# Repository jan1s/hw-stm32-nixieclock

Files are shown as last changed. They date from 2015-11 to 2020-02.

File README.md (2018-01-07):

# hw-nixieclock

The firmware running on the clock: [Firmware](https://github.com/jan1s/fw-clock)

A small Gist to configure a STM32 toolchain on Mac: [Toolchain](https://jan1s.github.io)

To flash the controller a STM32 Programmer is needed, just get the cheapest one from China.

## Initial Configuration

Before the clock will actually start working, it is necessary to set the type:

```bash
nixie_settype <type>
nixie_settype <type(0-4)>
```

Where `<type>` is a number defining the nixie clock type.

1. ZM1000
2. Z570M, IN-8
3. ZM1325
4. IN-14, ZM1020

It is also required to set the mode of operation:

```bash
nixie_setmode <mode>
nixie_setmode <mode(0=NONE|1=HHMMSS|2=HHMM|3=MMSS|4=YYYY)>
```

Where `<mode>` is a number defining the nixie operation mode.

1. HH:MM:SS
2. HH:MM
3. MM:SS
4. YYYY

## PCBs

The clock has seperate control and display pcbs. Those pcbs do not only form a basic case for the electronics, but also allow for flexible use with different tubes.

[Control PCBs](layout/control)

[Display PCBs](layout/display)

[Source PCBs](layout/source)

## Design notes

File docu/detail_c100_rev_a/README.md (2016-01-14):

# rev. a prototype in detail

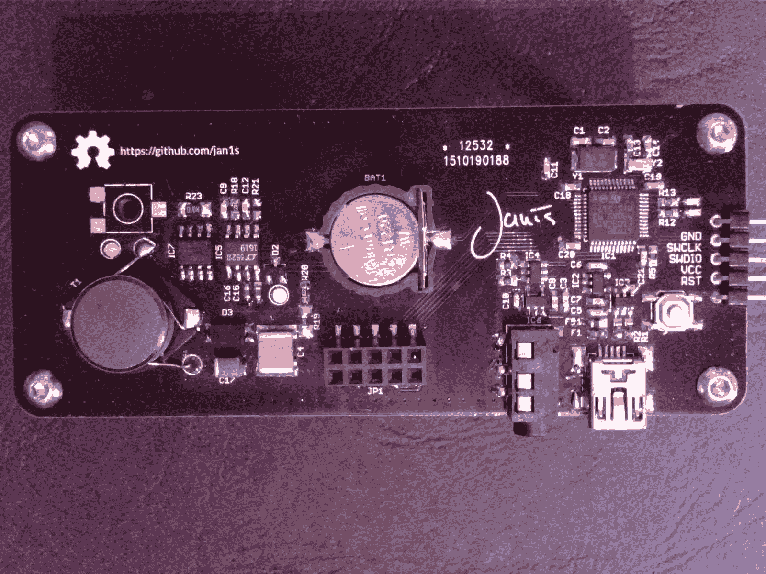
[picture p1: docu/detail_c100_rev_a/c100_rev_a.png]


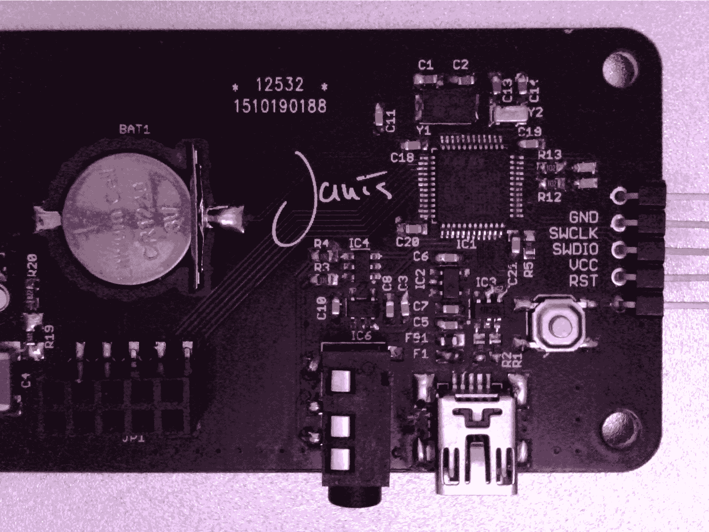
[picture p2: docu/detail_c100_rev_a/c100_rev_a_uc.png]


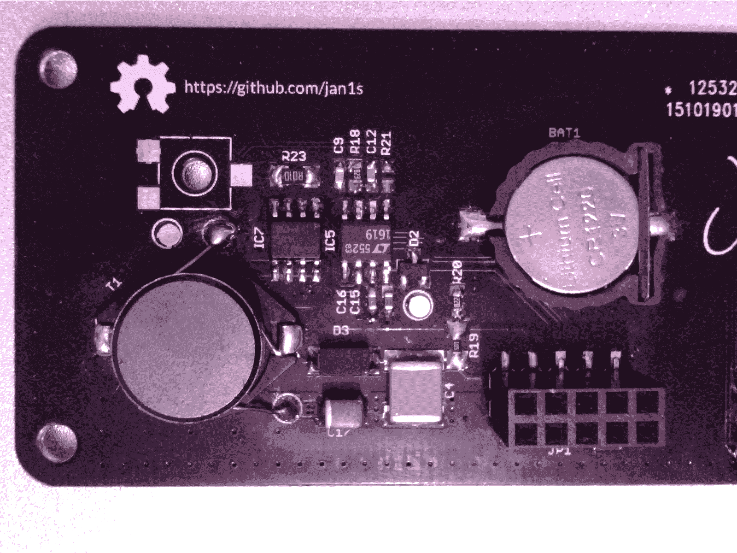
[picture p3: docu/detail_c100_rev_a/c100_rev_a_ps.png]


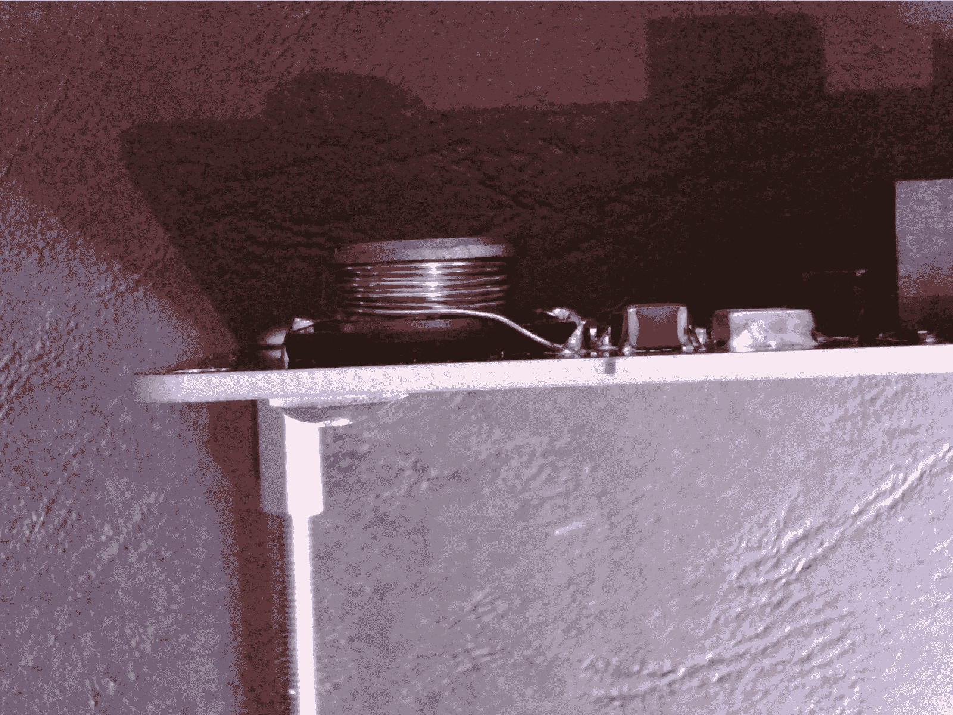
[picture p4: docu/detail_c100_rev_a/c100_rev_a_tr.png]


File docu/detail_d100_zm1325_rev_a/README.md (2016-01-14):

# rev. a prototype in detail

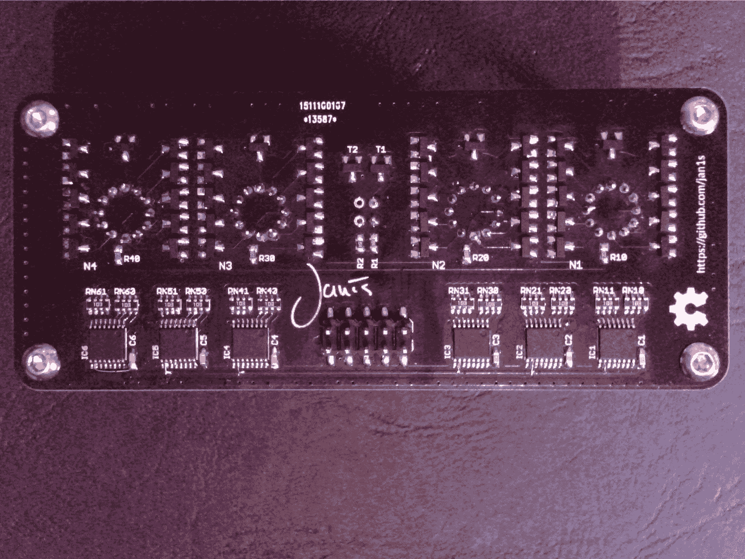
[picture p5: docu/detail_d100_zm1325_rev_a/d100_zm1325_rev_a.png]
Display PCB


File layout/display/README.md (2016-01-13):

# Display PCBs

## d100

The display boards with 100mm width use a smaller variant of the 74hc595 shift register.

### d100 ZM1000

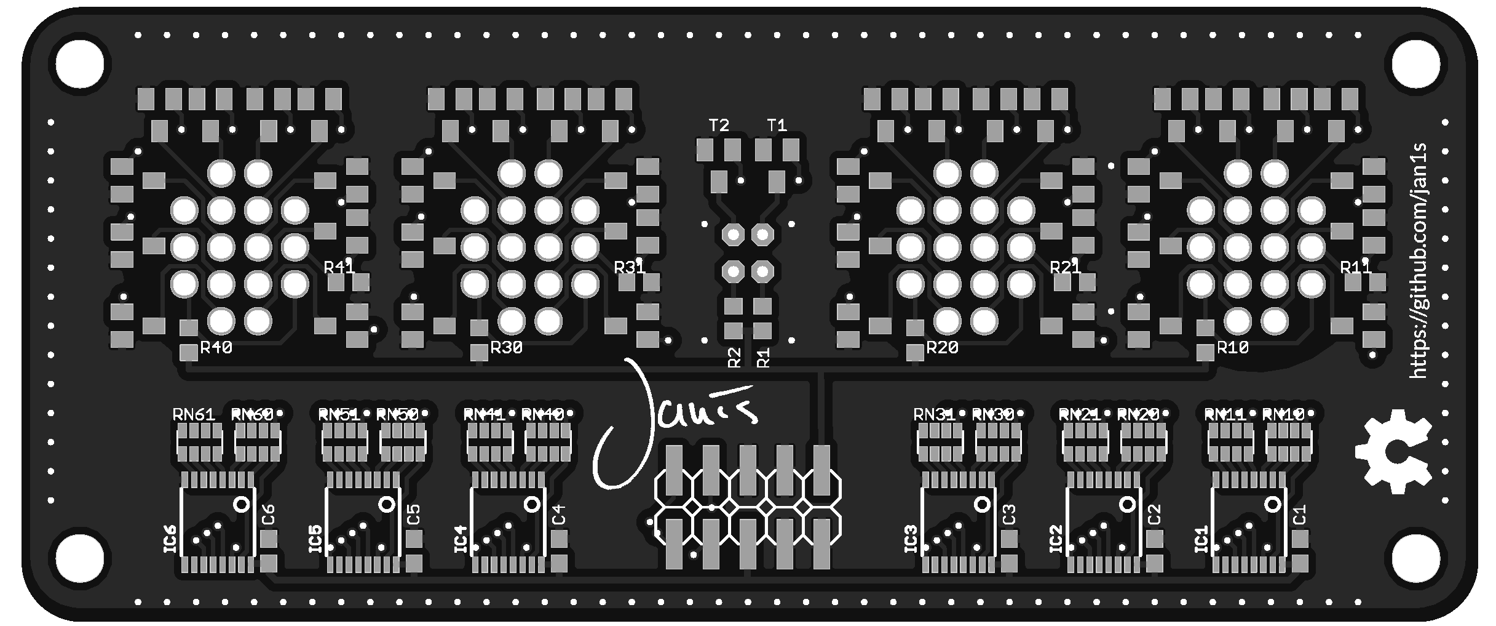
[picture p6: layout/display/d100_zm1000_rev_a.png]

rev. a

In rev a of the PCB is an error. (This is the version from the 32C3 workshop)
Find detailed pictures of the first prototype [here](../../docu/detail_d100_zm1325_rev_a).

* SCL of the shift registers are floating, they need to be connected to 5V

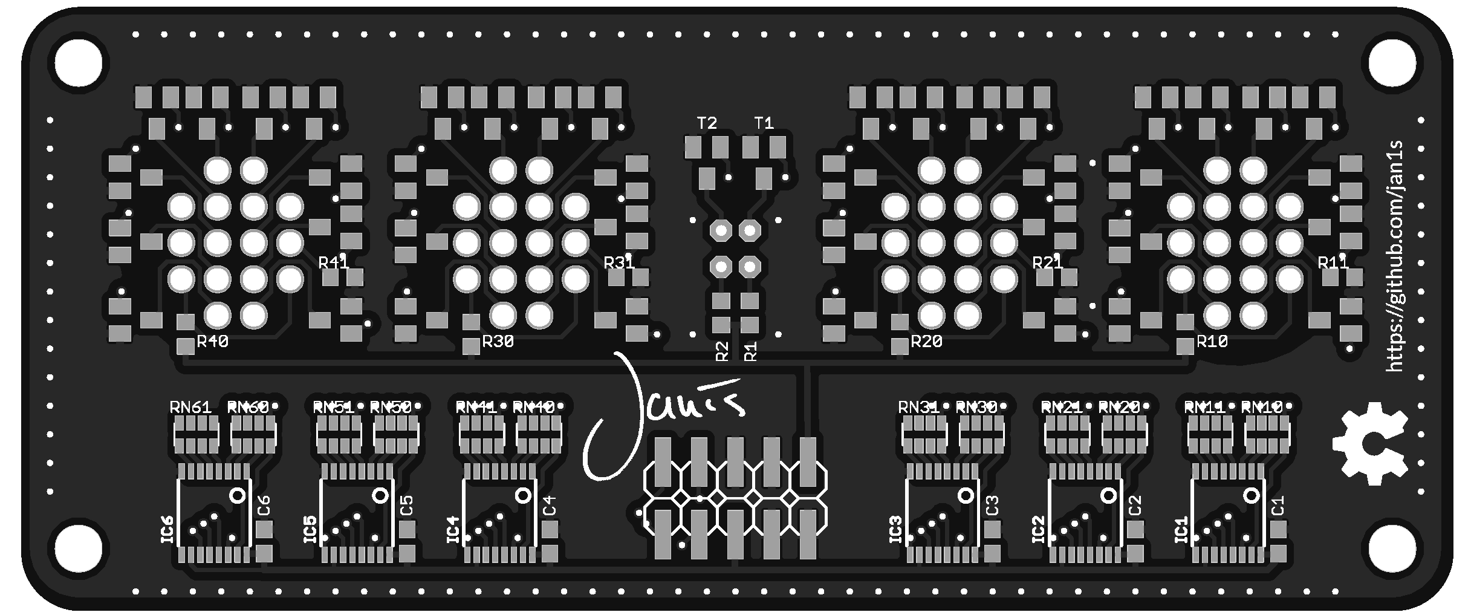
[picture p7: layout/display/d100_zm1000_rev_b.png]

rev. b

### d100 ZM1325

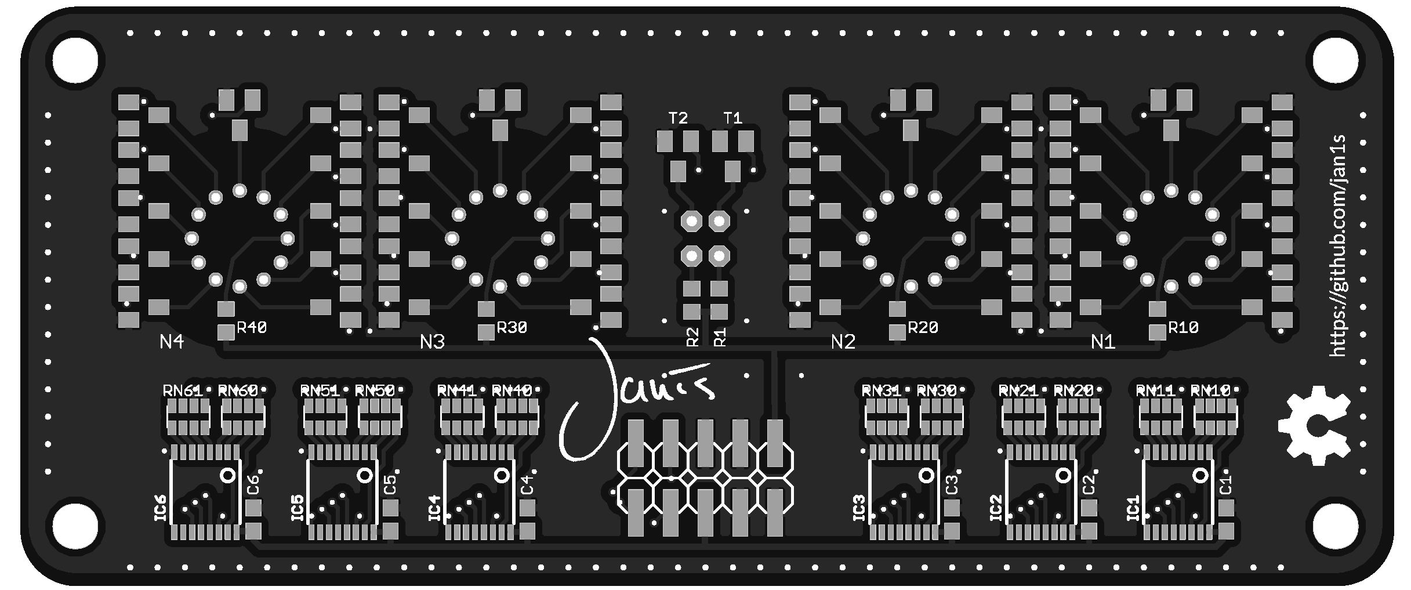
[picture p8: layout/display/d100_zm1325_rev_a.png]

rev. a

In rev a of the PCB is an error. (This is the version from the 32C3 workshop)

* SCL of the shift registers are floating, they need to be connected to 5V

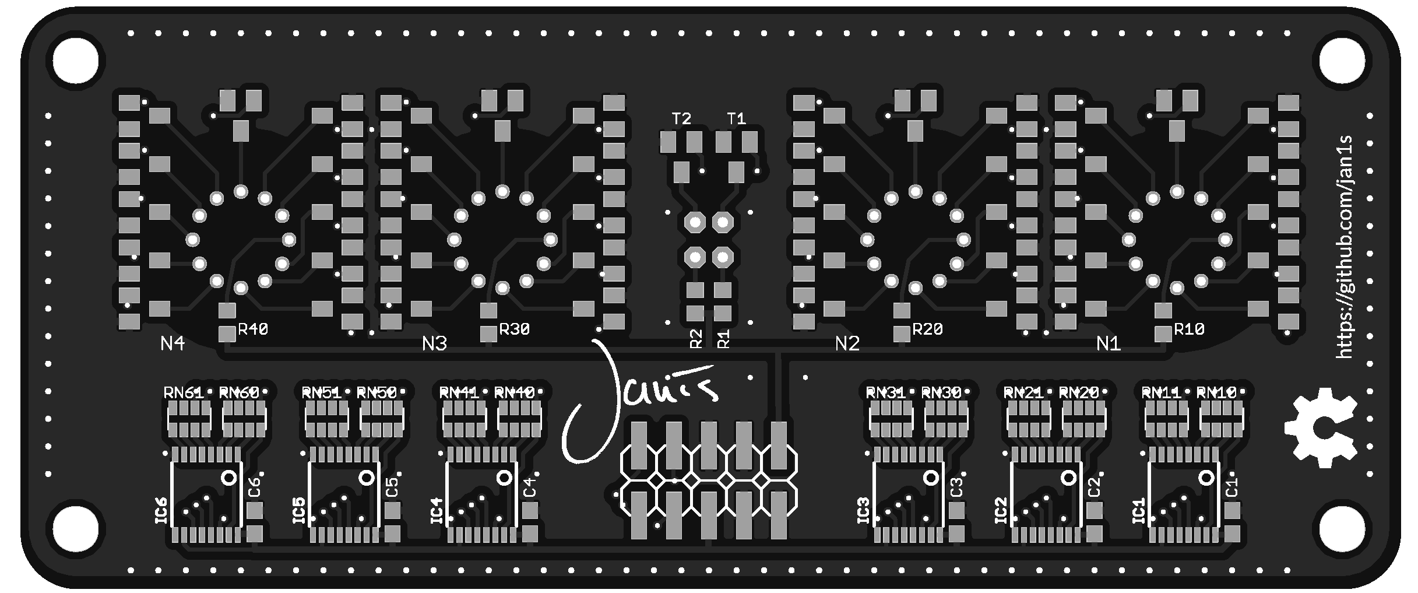
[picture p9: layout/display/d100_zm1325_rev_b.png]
 
rev. b

### d100 BOM

| Identifier | Type/Value | Quantity | [Reichelt][reichelt] | [Digikey][digikey] | Comment |
| --- | --- | --- | --- | --- | --- |
| R1-R2 | 220 kΩ | 2 | SMD-0603 220K |  |
| R10-R46 | 22 kΩ | 4 | SMD-0603 22K |  |
| RN10-RN61| 4x10 kΩ | 12 | BCN16 10K |  |
| C1-C6 | 100 nF | 6 | X7R-G0603 100N |  |
| T1-T69 | SMBTA 42 SMD | 46 | SMBTA 42 SMD | SMBTA42E6327INCT-ND |
| IC1-IC6 | 74HC595PW | 6 |  | 568-2263-1-ND |
| JP1 | 2x5pol Header | 1 | SL 2X10G SMD2,54 | 609-4723-ND |
| GL1, GL2 | Neon Bulb | 2 | GLIMMLAMPE | C2A-ND |

##d150

The display boards with 150mm width use 8 74hc595d shift registers.

### d150 ZM1000

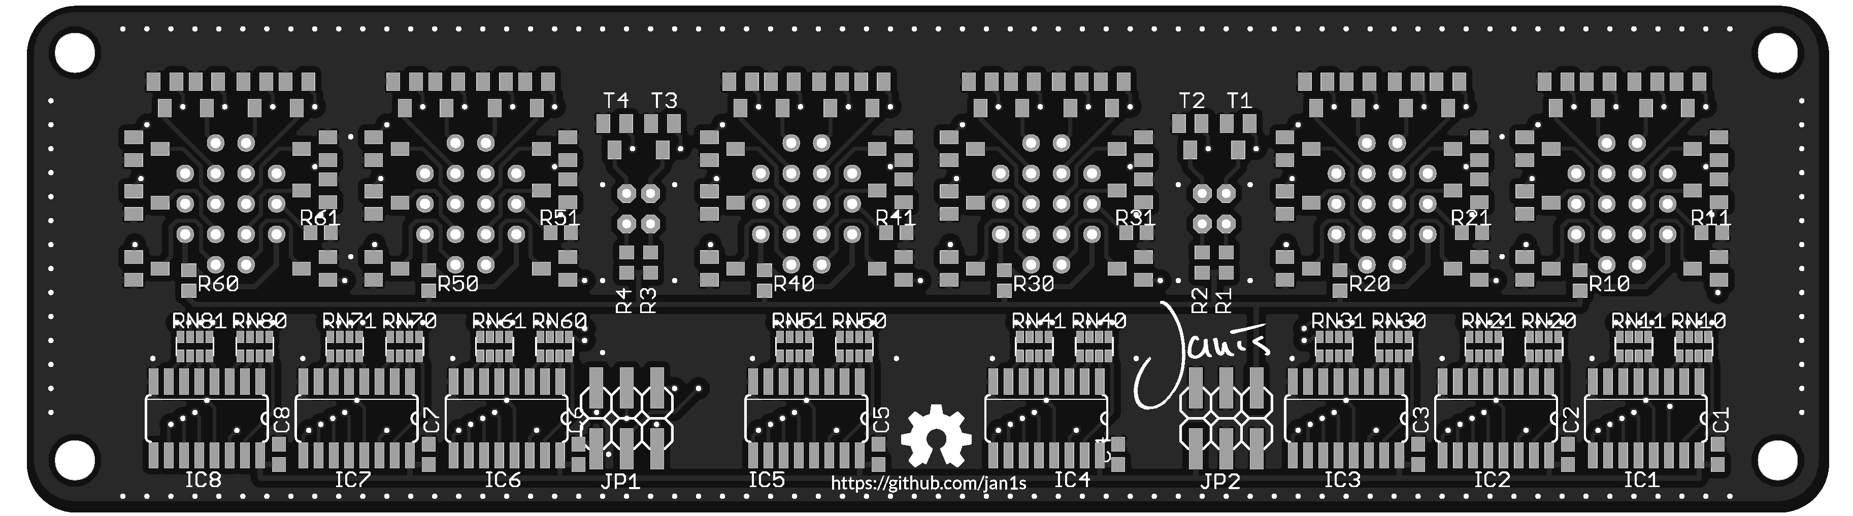
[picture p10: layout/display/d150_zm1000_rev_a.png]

rev. a

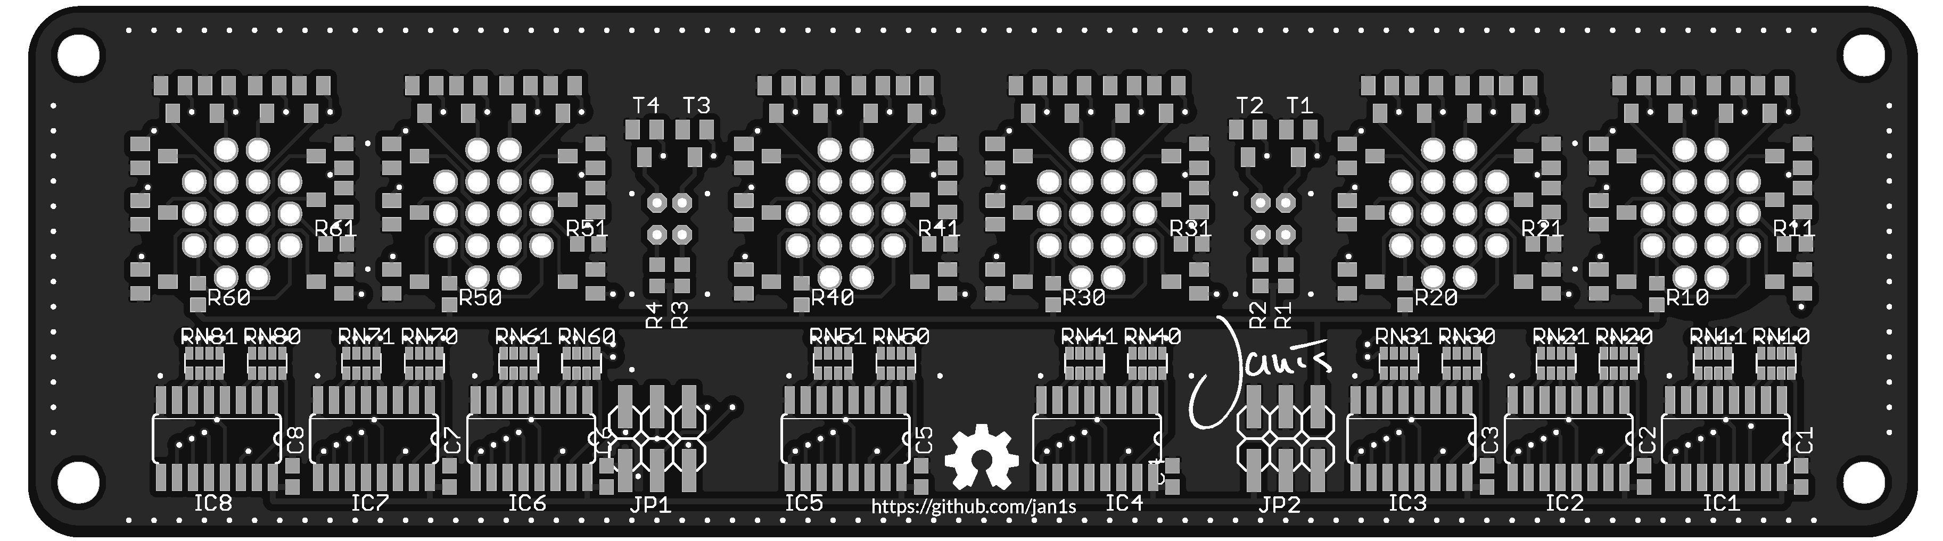
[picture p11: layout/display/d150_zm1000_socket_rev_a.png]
 
rev. a, socketed

### d150 Z570M

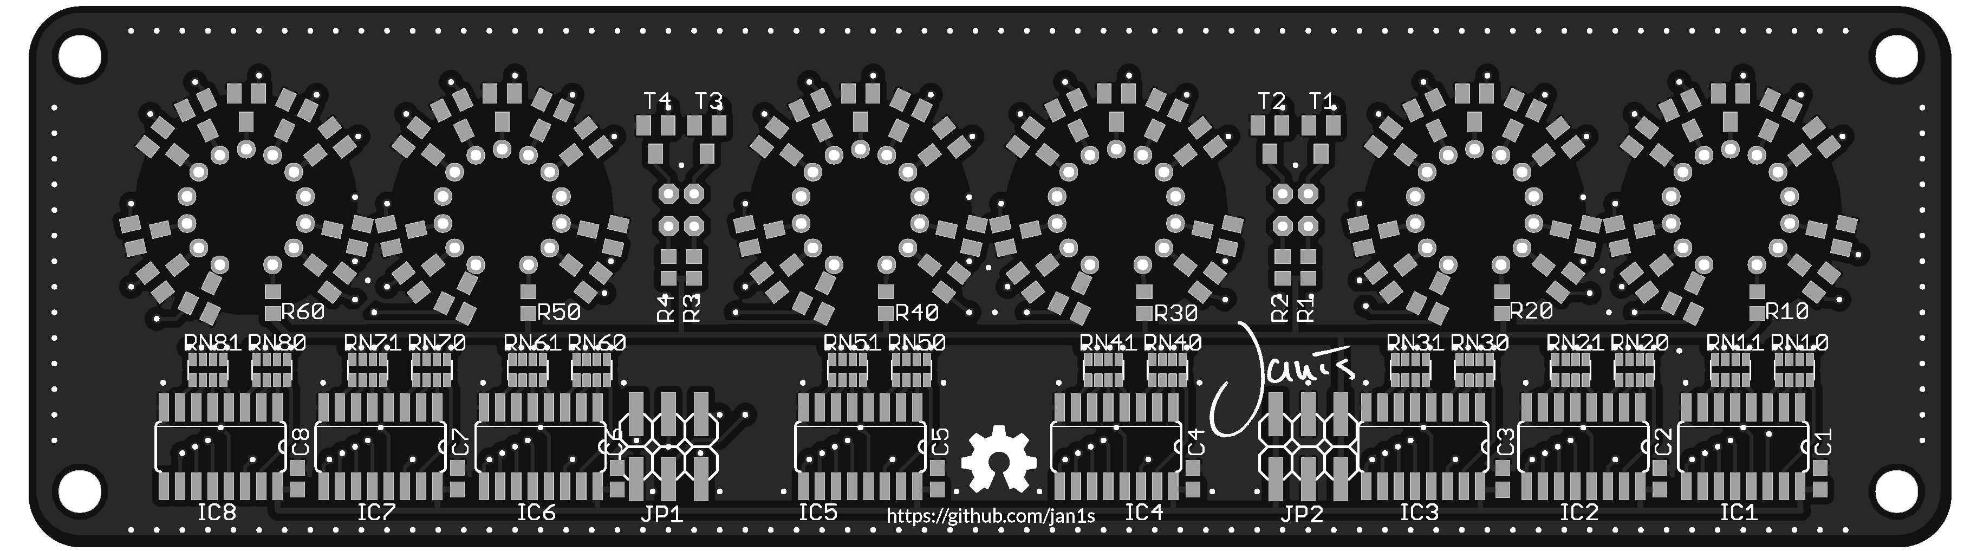
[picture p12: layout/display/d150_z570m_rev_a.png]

rev. a

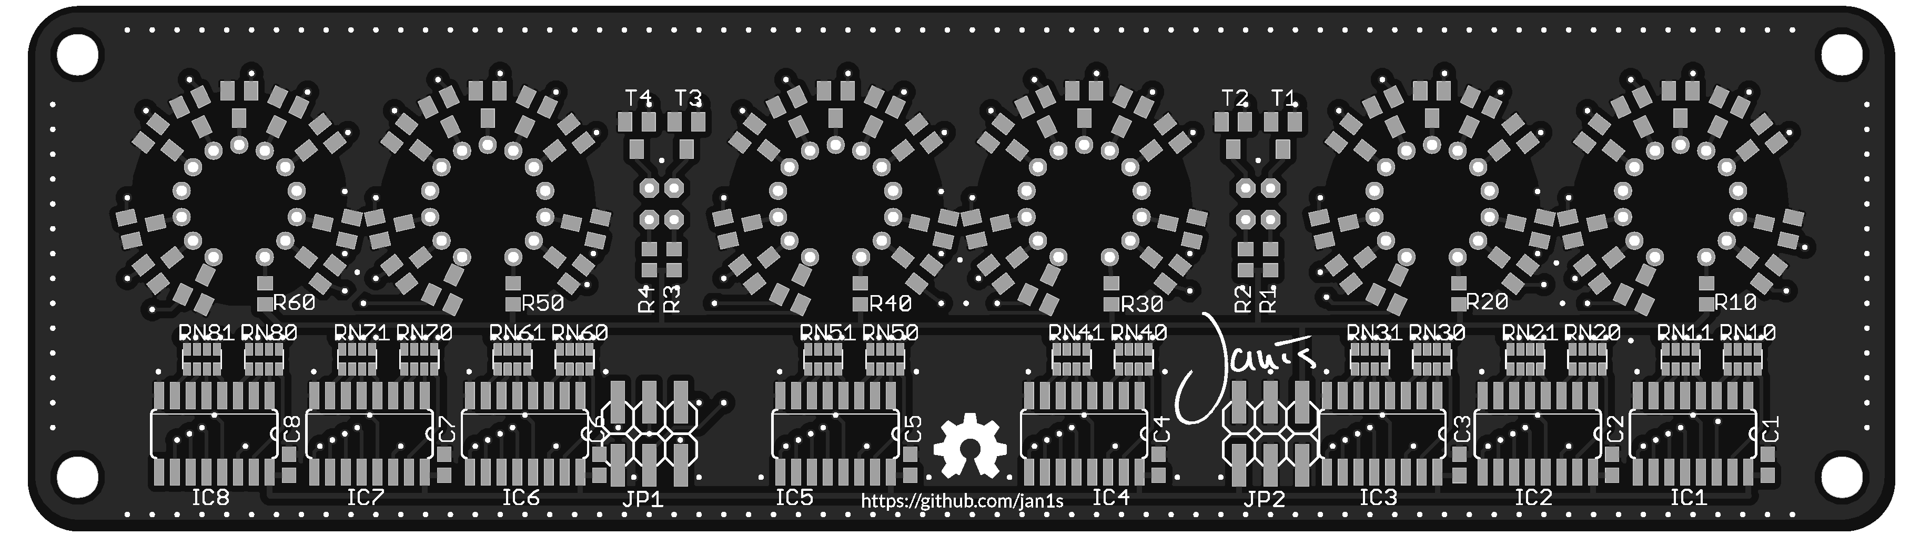
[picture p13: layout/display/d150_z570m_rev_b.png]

rev. b

### d150 IN-8

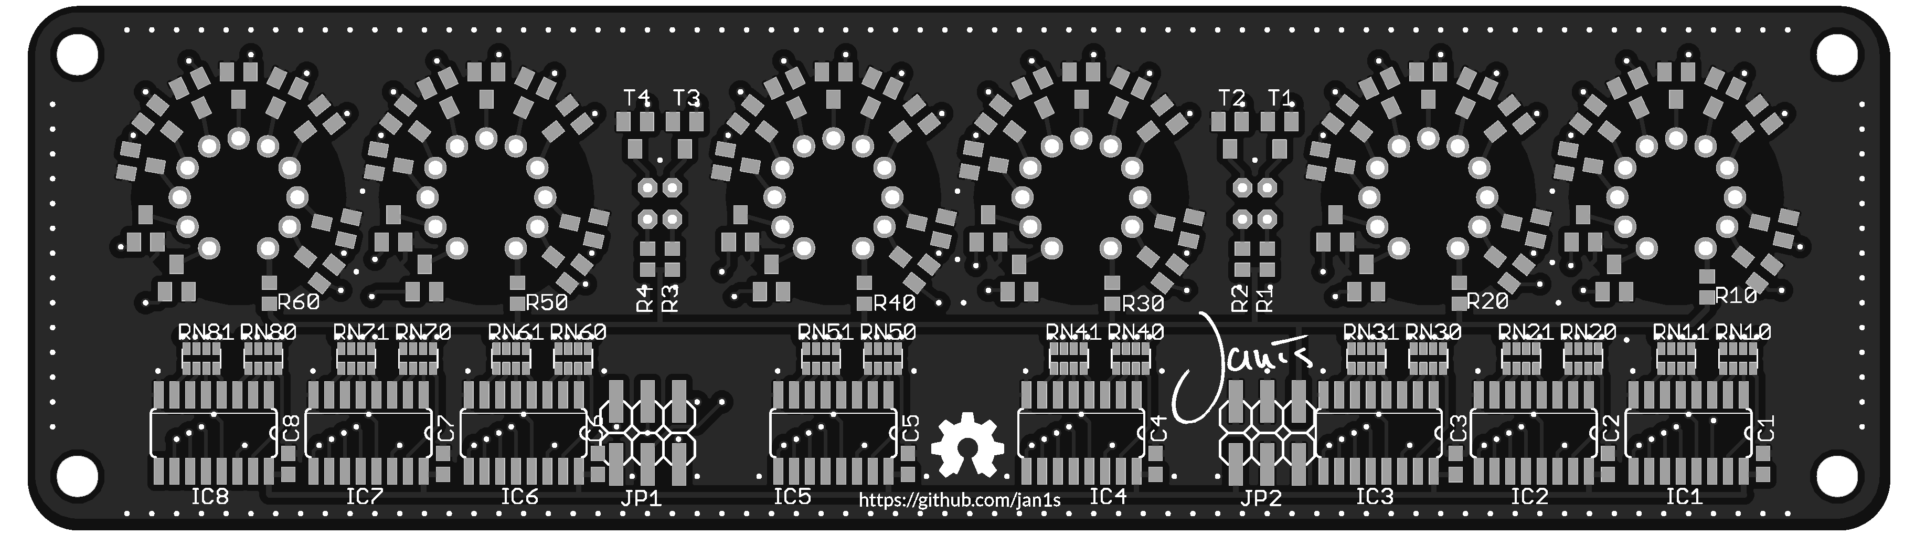
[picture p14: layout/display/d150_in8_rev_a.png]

rev. a

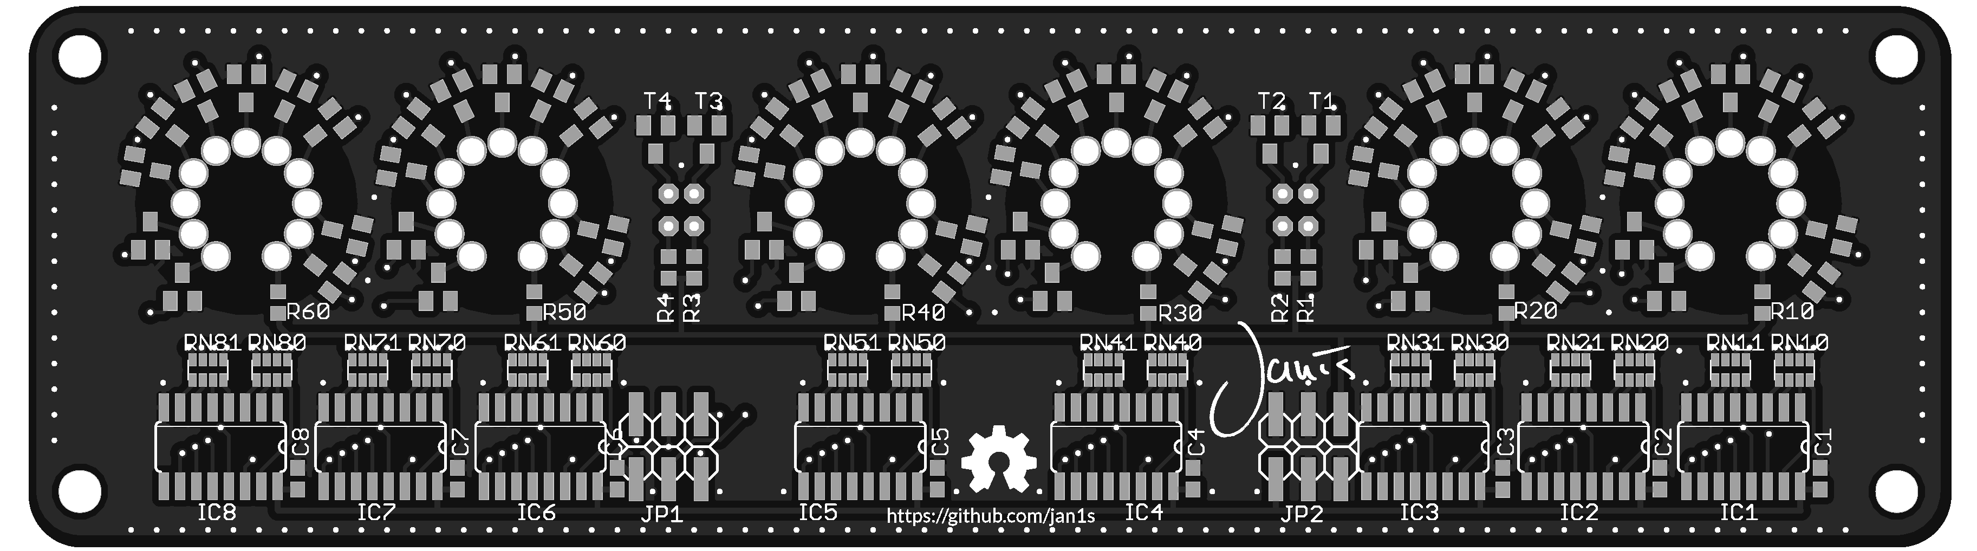
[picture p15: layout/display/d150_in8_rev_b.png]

rev. b

### d150 IN-8-2

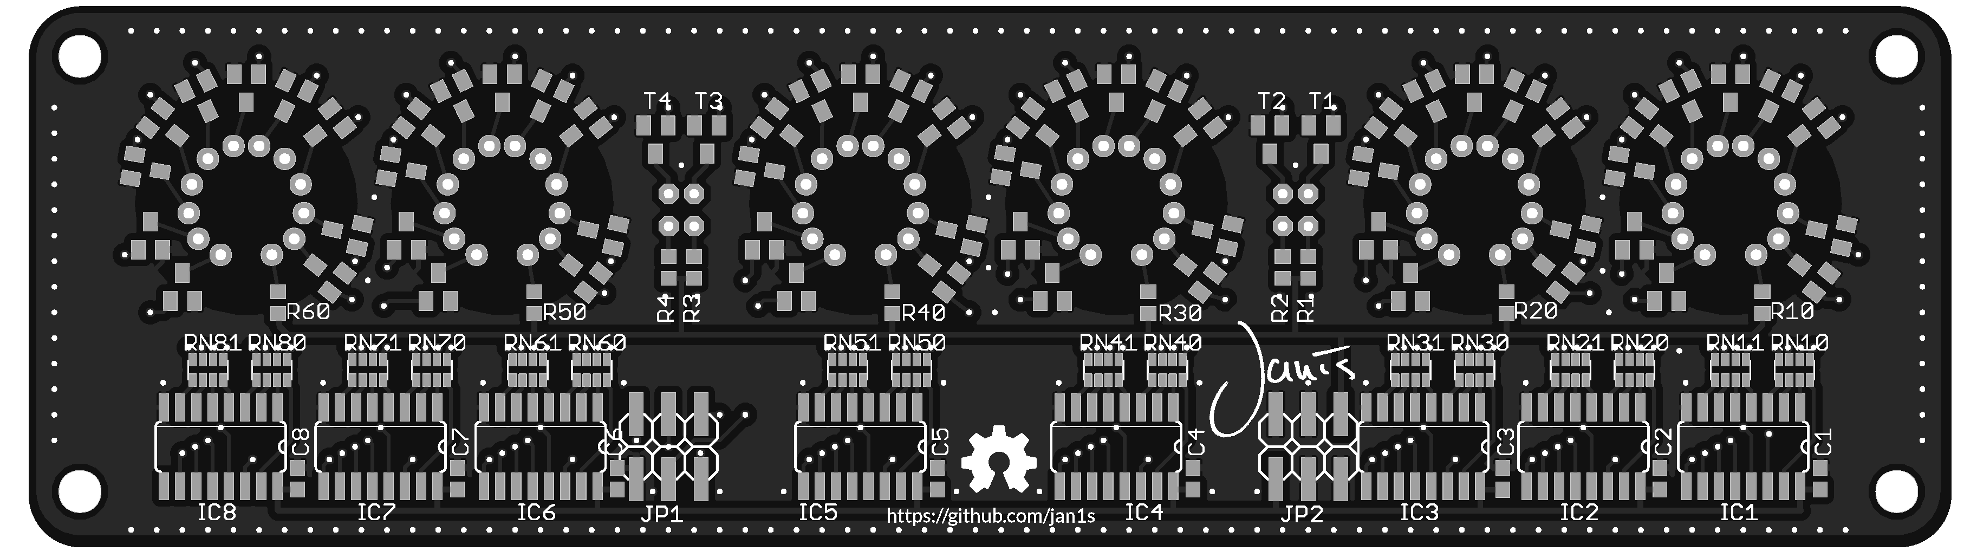
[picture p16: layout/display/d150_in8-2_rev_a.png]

rev. a

### d150 IN-14

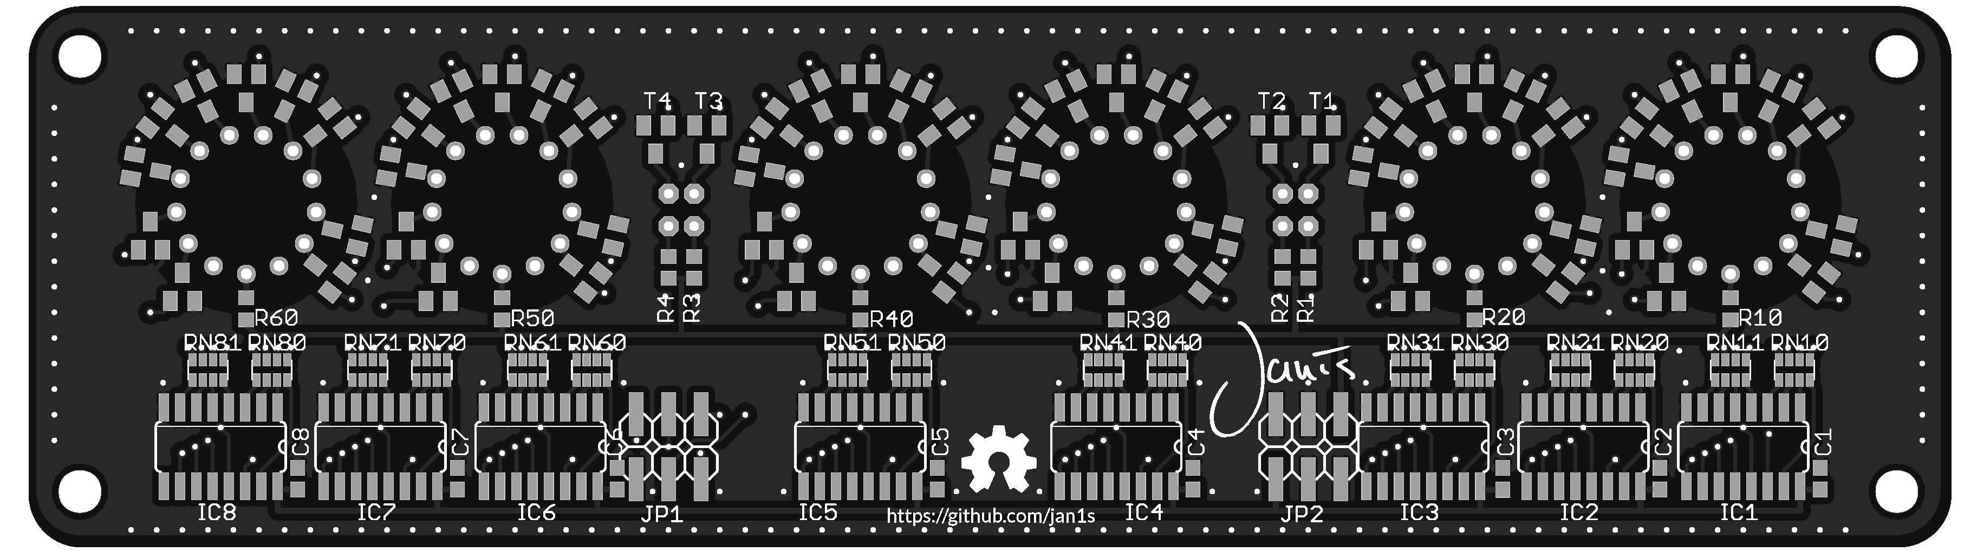
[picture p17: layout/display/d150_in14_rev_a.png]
 
rev. a

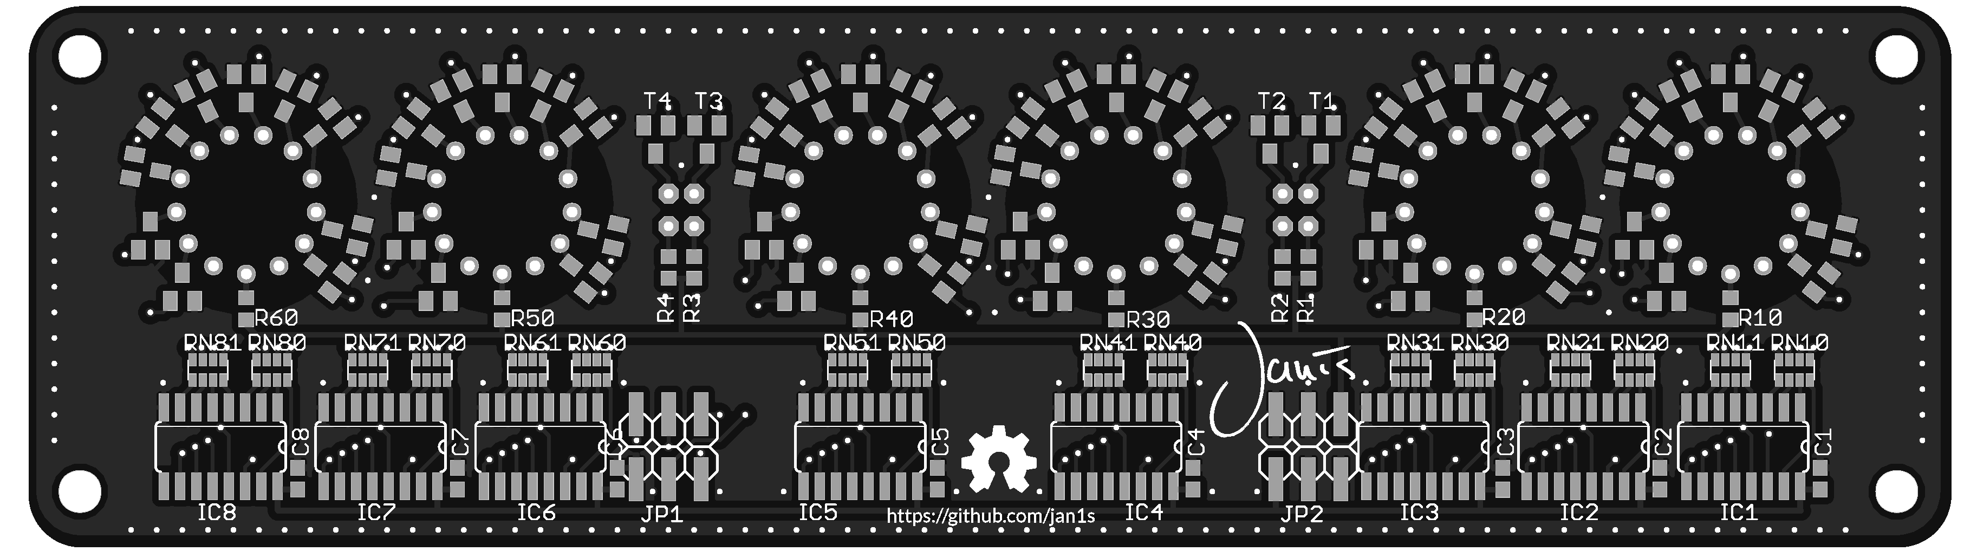
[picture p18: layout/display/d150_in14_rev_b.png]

rev. b

### d150 BOM

| Identifier | Type/Value | Quantity | [Reichelt][reichelt] | [Digikey][digikey] | Comment |
| --- | --- | --- | --- | --- | --- |
| R1-R4 | 220 kΩ | 4 | SMD-0603 220K |  |
| R10-R60 | 22 kΩ | 6 | SMD-0603 22K |  |
| RN10-RN81| 4x10 kΩ | 16 | BCN16 10K |  |
| C1-C8 | 100 nF | 8 | X7R-G0603 100N |  |
| T1-T69 | SMBTA 42 SMD | 64 | SMBTA 42 SMD | SMBTA42E6327INCT-ND |
| IC1-IC8 | 74HC595D | 8 | SMD HC 595 | |
| JP1, JP2 | 2x3pol Header | 2 | SL 2X10G SMD2,54 | |
| GL1-GL4 | Neon Bulb | 4 | GLIMMLAMPE | C2A-ND |

[reichelt]: http://www.reichelt.de
[digikey]: http://www.digikey.de
[mouser]: http://mouser.com
[aliexpress]: http://www.aliexpress.com

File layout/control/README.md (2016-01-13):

# Control PCBs

## c100

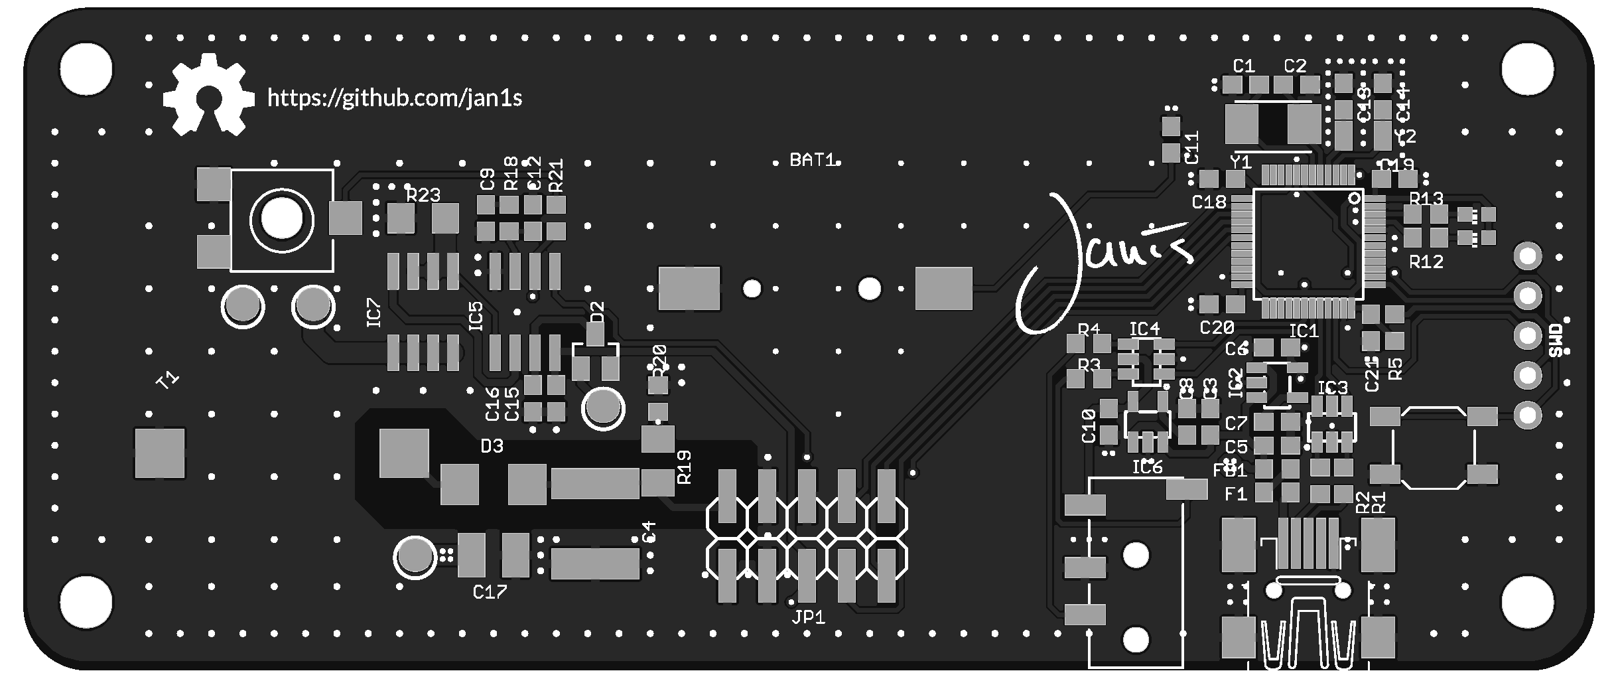
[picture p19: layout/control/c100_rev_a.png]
Control PCB

rev. a

In the first revision of the PCBs are some minor errors. (This is the version from the 32C3 workshop)
Find detailed pictures of the first prototype [here](../../docu/detail_c100_rev_a).

* A pullup resistor is missing on the USB data lines
* LED silkscreen missing, they are on the right of the controller

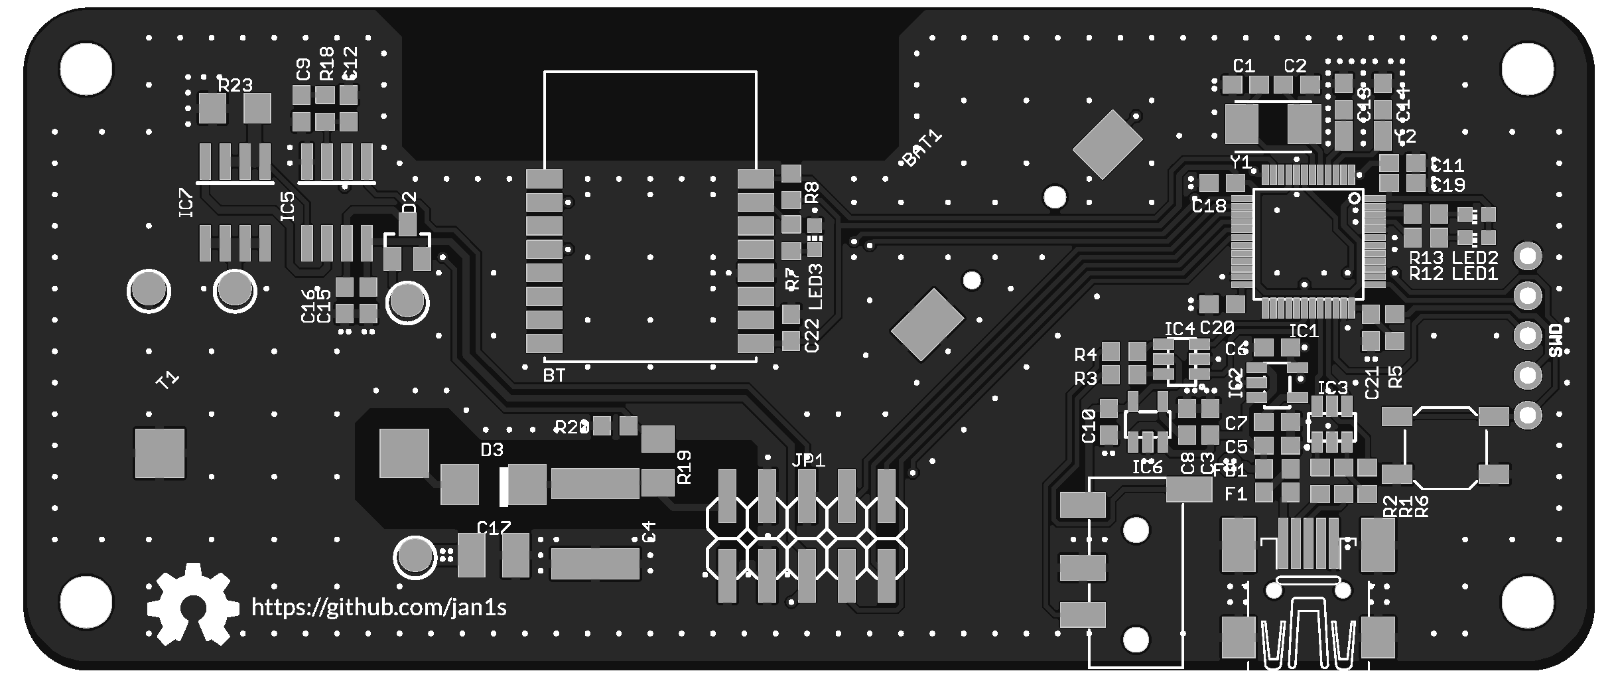
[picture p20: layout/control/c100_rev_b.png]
Control PCB

rev. b

## c150

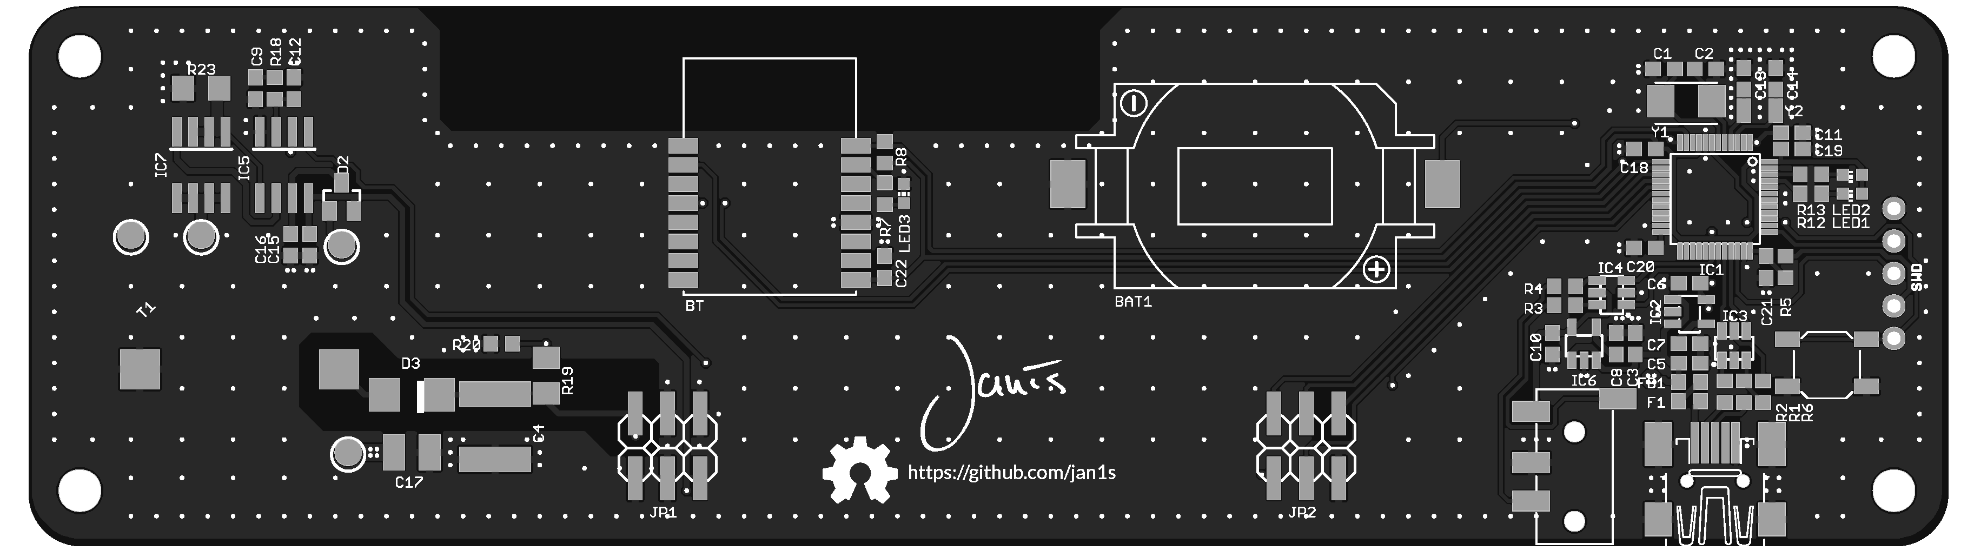
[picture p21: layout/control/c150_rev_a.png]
Control PCB

rev. a

### control BOM
| Identifier | Type/Value | Quantity | [Reichelt][reichelt] | [Digikey][digikey] | Comment |
| :--- | :--- | :--- | :--- | :--- | :--- |
| R1, R2, R3, R4 | 33 Ω | 4 | SMD-0603 33 | 311-33GRCT-ND |
| R12, R13 | 1 kΩ | 2 | SMD-0603 1,00K | 311-1.0KGRCT-ND |
| C1, C2, C13, C14 | 10 pF | 4 | NPO-G0603 10P |  |
| C7, C8 | 10 nF | 2 | X7R-G0603 10N |  |
| C18, C19, C20, C21 | 100 nF | 4 | X7R-G0603 100N |  |
| C3, C5, C6, C10, C11 | 10 µF | 5 | X5R-G0603 10/6 |  |
| FB1 | Ferrite Bead | 1 | BLM18AG 121 | 490-1011-1-ND |
| Y1 | 8MHz | 1 | - | 535-10630-1-ND |
| Y2 | 32kHz | 1 | 32,768 PGD-9 | 535-9542-1-ND |
| LED1 | LED green | 1 | LG L29K |  |
| LED2 | LED white | 1 | LW L283 | |
| BAT1 | Batteryholder | 1 | - | BC501SM-ND | c100 |
| BAT1 | Batteryholder | 1 | KZH 20SMD-2 | - | c150 |
| BAT | CR 1220 | 1 | CR 1220 VAR | SY033-ND |
| SW1 | Tact Switch Top | 1 | - | EG2531CT-ND |
| J1 | 2x5 Socket | 1 | - | A100866TR-ND, S5714-ND |
| J2 | USB Jack | 1 | USB BWM SMD | 151-1206-1-ND |
| IC1 | STM32F103C8T6 | 1 | STM32 F103C8T6 | 497-6063-ND |
| IC2, IC6 | LP2985 | 1 | LP 2985 IM5-3,3 |  |
| IC3, IC4 | USBLC6-2 | 1 | - | 497-5235-1-ND |

### power supply BOM
| Identifier | Type/Value | Quantity | [Reichelt][reichelt] | [Digikey][digikey] | Comment |
| --- | --- | --- | --- | --- | --- |
| R23 | 0.01 Ω | 1 | - | RHM.10MCT-ND |
| R18 | 82 kΩ | 1 | SMD-0603 82K |  |
| R20 | 8,2 kΩ | 1 | SMD-0603 8,2K |  |
| R19 | 1 MΩ | 1 | SMD-1206 1M |  |
| C12 | 150 pF | 1 | NPO-G0603 150P |  |
| C9 | 22 nF | 1 | X7R-G0603 22N |  |
| C4 | 1 µF / 250V | 1 | 1u/250V | 490-3550-1-ND  | |
| C15, C16 | 10 µF | 2 | X5R-G0603 10/6 |  |
| C17 | 100 µF | 1 | X5R-G1210 100 |  |
| D2 | Diode | 1 | BAT 54C SMD |  |
| D3 | Diode | 1 | ES 2GA SMD |  |
| L2 | 680 µH | 1 | L-PISR 680µ |  |
| IC7 | IRF 7470 | 1 | IRF 7470 | IRF7470PBFCT-ND |
| IC5 | LT1619ES8 | 1 | - | LT1619ES8#PBF-ND |

[reichelt]: http://www.reichelt.de
[digikey]: http://www.digikey.de
[mouser]: http://mouser.com
[aliexpress]: http://www.aliexpress.com

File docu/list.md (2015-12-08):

# Nixieclock Workshop

&nbsp;

## Control PCB

| Identifier | Type/Value | Quantity | 
| :--- | :--- | :--- |
| PCB1 | Control PCB | 1 |
| R1, R2, R3, R4 | 33 Ω | 4 | 
| R12, R13 | 1 kΩ | 2 |
| C1, C2, C13, C14 | 10 pF | 4 |
| C7, C8 | 10 nF | 2 | 
| C18, C19, C20, C21 | 100 nF | 4 |
| C3, C5, C6, C10, C11 | 10 µF | 5 |
| L1 | Ferrite Bead | 1 |
| Y1 | 8MHz | 1 |
| Y2 | 32kHz | 1 |
| LED1 | LED green | 1 | 
| LED2 | LED white | 1 |
| IC1 | STM32F103C8T6 | 1 |
| IC2, IC6 | LP2985 | 2 |
| IC3, IC4 | USBLC6-2 | 2 |
| BAT1 | Batteryholder | 1 |
| BAT | CR 1220 | 1 |
| SW1 | Tact Switch Top | 1 |
| J1 | 2x5 Socket | 1 |
| J2 | USB Jack | 1 |
| J3 | TRS Jack | 1 |

## Power supply
| Identifier | Type/Value | Quantity | 
| :--- | :--- | :--- |
| R23 | 0.01 Ω | 1 | 
| R20 | 8,2 kΩ | 1 |
| R18 | 82 kΩ | 1 |
| R19 | 1 MΩ | 1 |
| C12 | 150 pF | 1 |
| C9 | 22 nF | 1 |
| C4 | 1 µF / 250V | 1 |
| C15, C16 | 10 µF | 2 |
| C17 | 100 µF | 1 |
| D2 | BAT54C | 1 |
| D3 | ES 2GA | 1 |
| T1 | IRF 7470 | 1 | 
| IC5 | LT1619ES8 | 1 |
| L2 | 680 µH | 1 |
| K1 | Kapton Tape | 1 |
| CW1 | Copper Wire | 1 |

&nbsp;

&nbsp;

&nbsp;

&nbsp;

&nbsp;

&nbsp;

&nbsp;

&nbsp;

## Display PCB
| Identifier | Type/Value | Quantity |
| :--- | :--- | :--- |
| PCB2 | Display PCB | 1 |
| R1, R2 | 220 kΩ | 2 |
| R10-R40 | 22 kΩ | 4 |
| RN10-RN71| 4x10 kΩ | 12 |
| C1-C6 | 100 nF | 6 |
| T1-T49 | SMBTA 42 SMD | 46 |
| IC1-IC6 | 74HC595PW | 6 |
| JP1 | 2x5pol Header | 1 |
| GL1, GL2 | Neon Bulb | 2 |

&nbsp;

&nbsp;

&nbsp;

&nbsp;

&nbsp;

&nbsp;

## Other
| Identifier | Type/Value | Quantity | 
| :--- | :--- | :--- |
| - | Screws M3 | 8 |
| - | Spacer bolts | 4 |
| - | Feet | 4 |

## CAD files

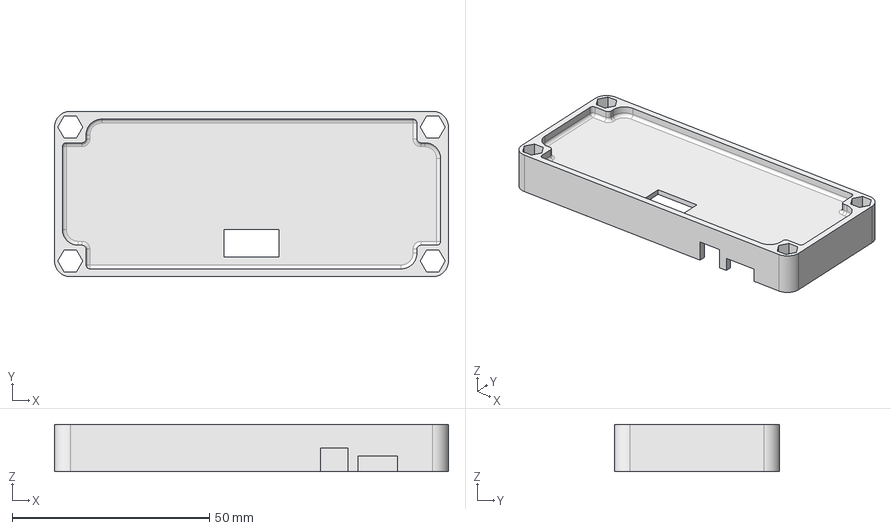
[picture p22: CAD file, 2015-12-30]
case/ncase_rev_a.FCStd
100.0 x 42.0 x 12.0 mm

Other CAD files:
case/ncase_rev_a.stl

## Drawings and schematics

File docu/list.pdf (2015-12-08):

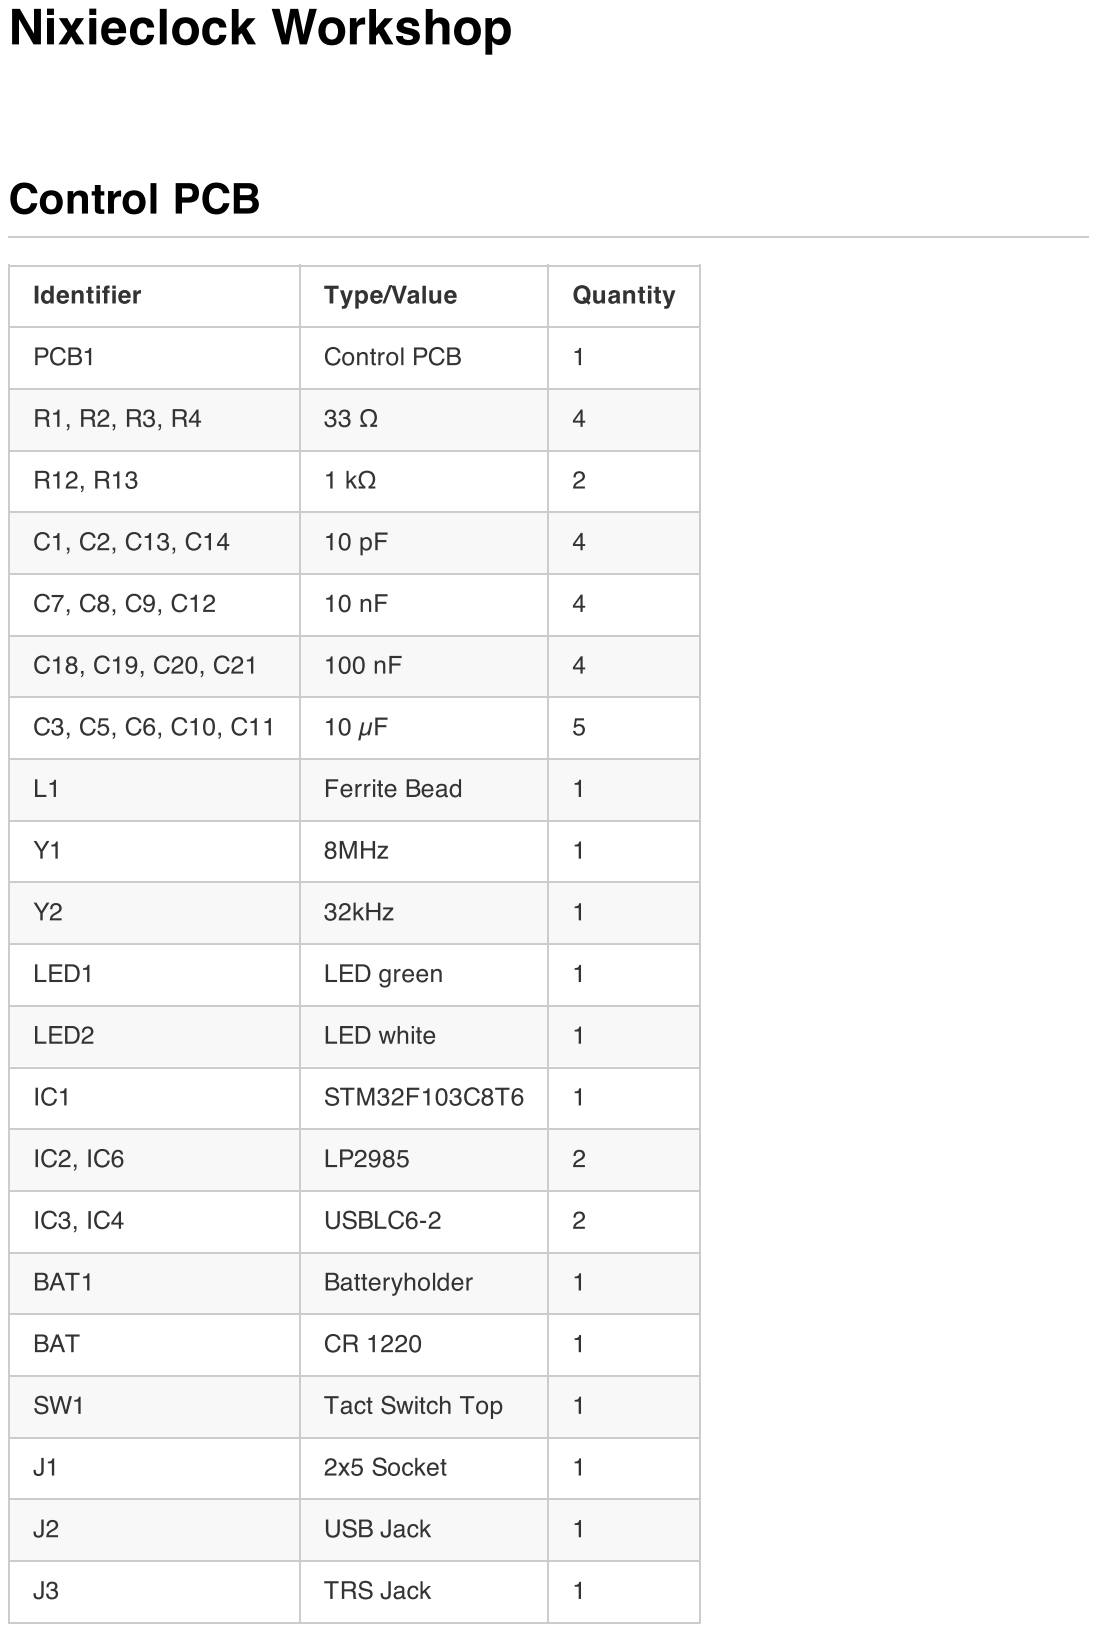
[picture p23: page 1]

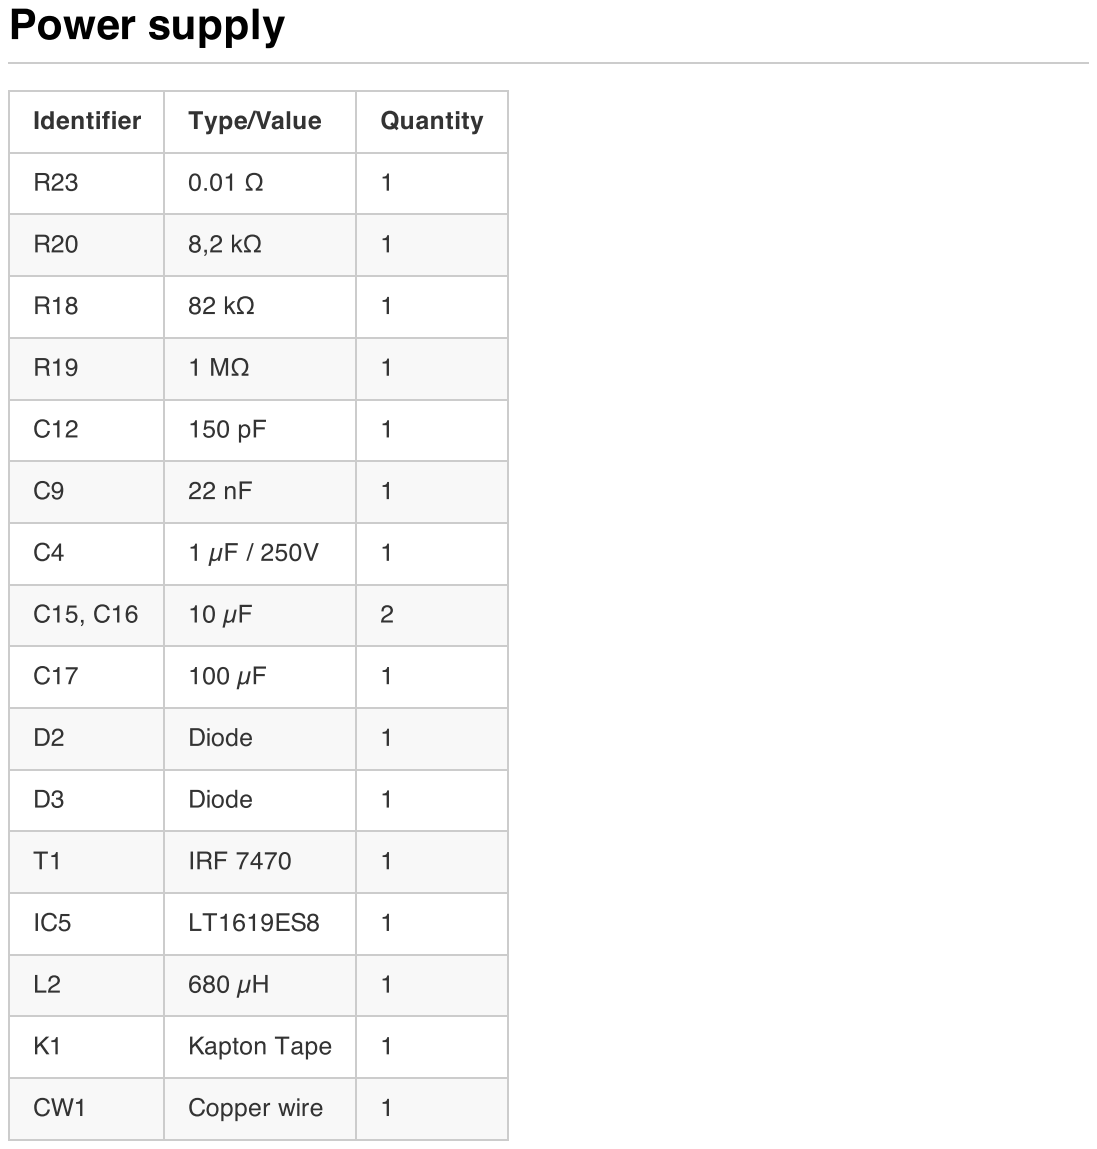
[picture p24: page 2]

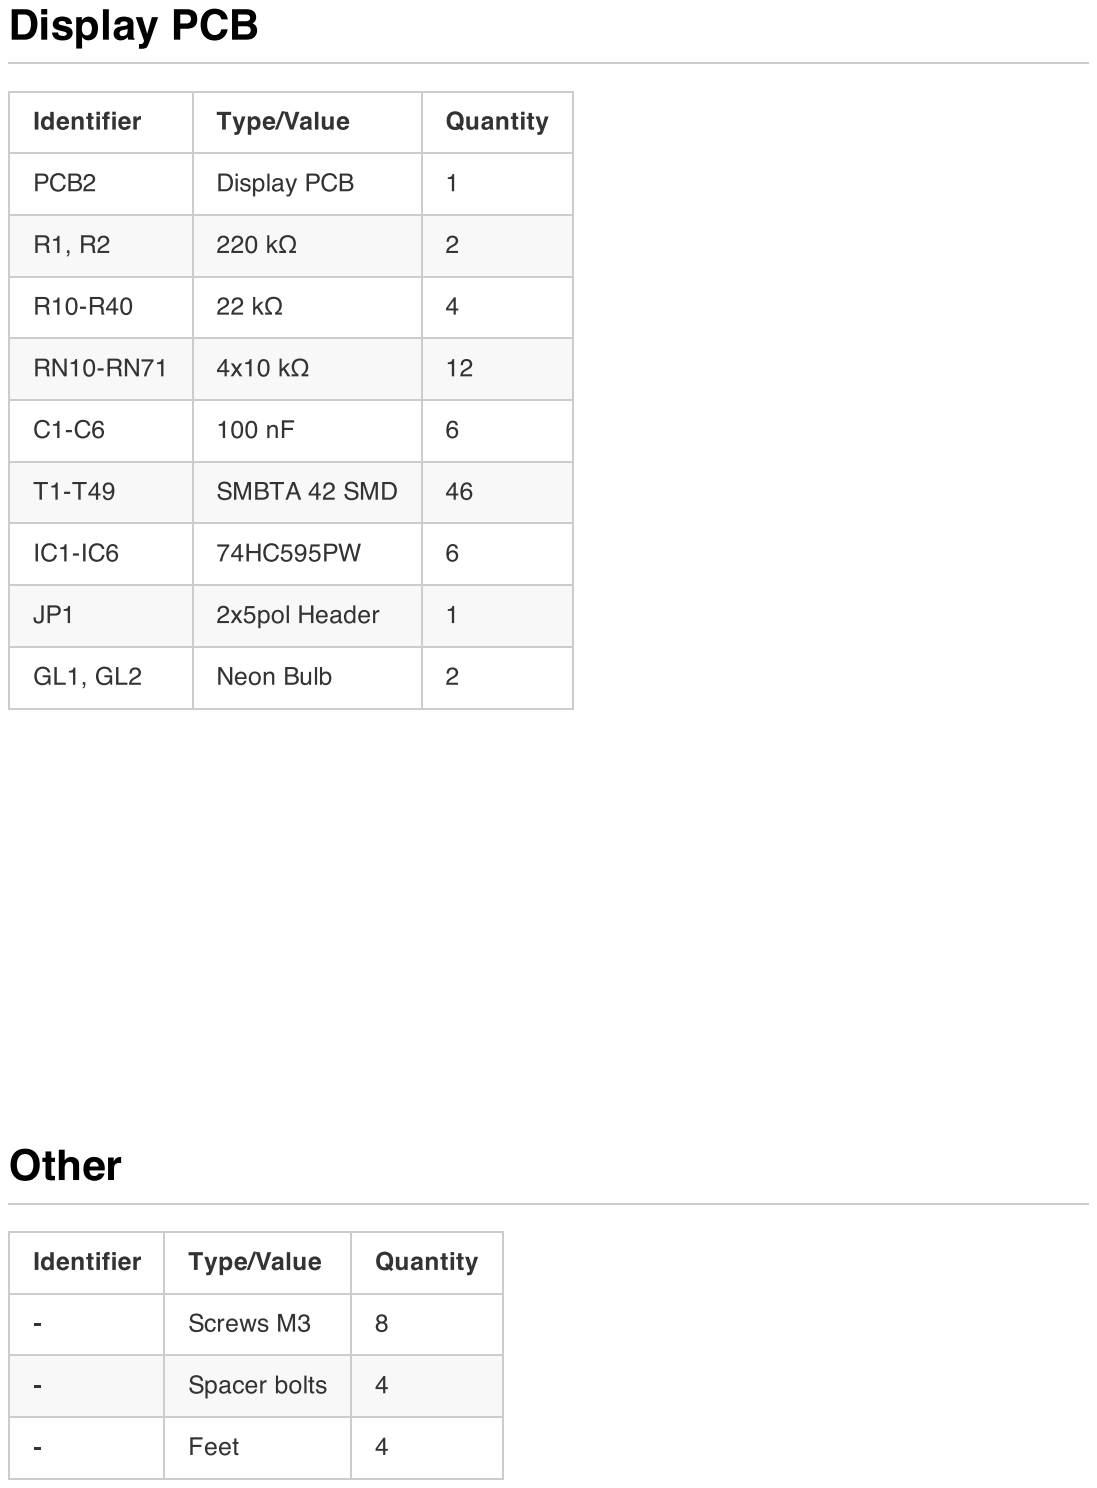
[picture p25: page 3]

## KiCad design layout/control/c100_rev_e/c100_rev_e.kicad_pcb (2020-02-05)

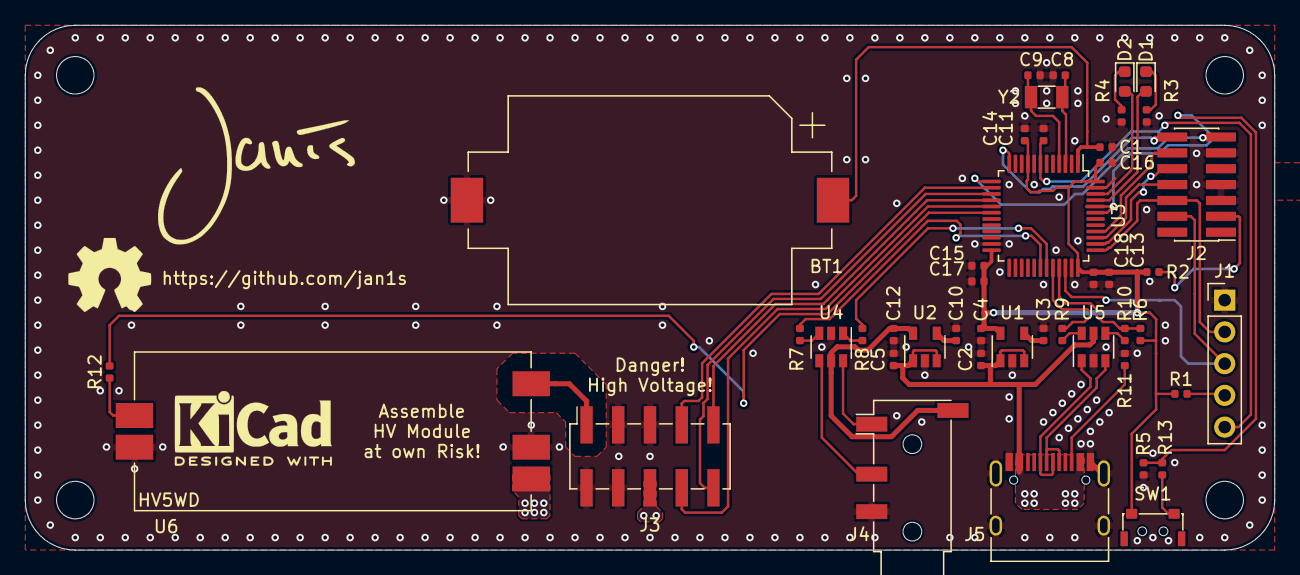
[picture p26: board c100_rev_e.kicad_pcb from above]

Board: 2 copper layers, 100.0 x 42.0 mm, 45 parts (0 on the bottom side), 45 nets.

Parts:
BT1: Battery_Cell; BatteryHolder_Keystone_1060_1x2032
C1, C17: 1uF; C_0402_1005Metric
C2, C4, C5, C12, C13: 10uF; C_0402_1005Metric
C3, C10: 470pF; C_0402_1005Metric
C8, C9: 10p; C_0402_1005Metric
C11, C14, C15, C16, C18: 100nF; C_0402_1005Metric
D1, D2: LED White; LED_0603_1608Metric
J1: Conn_01x05; PinHeader_1x05_P2.54mm_Vertical
J2: STDC14; PinHeader_2x07_P1.27mm_Vertical_SMD
J3: Conn_02x05_Odd_Even; PinSocket_2x05_P2.54mm_Vertical_SMD
J4: AudioJack4_SwitchTR1; Jack_3.5mm_PJ320D_Horizontal
J5: USB_C_Receptacle_USB2.0; USB_C_Receptacle_HRO_TYPE-C-31-M-12
R1, R2, R5, R12: 10k; R_0402_1005Metric
R3, R4, R6: 1k5; R_0402_1005Metric
R7, R8, R9, R10, R13: 22R; R_0402_1005Metric
R11: 5k1; R_0402_1005Metric
SW1: SW_Push; 1TS003B
U1, U2: MIC5219-3.3YM5; SOT-23-5
U3: STM32F072C8Tx; LQFP-48_7x7mm_P0.5mm
U4, U5: USBLC6-2SC6; SOT-23-6
U6: HV5W; HV5W_SMD
Y2: 32.768kHz; Crystal_SMD_3215-2Pin_3.2x1.5mm

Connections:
+3.3V_TRS: C12.1, J4.S, U2.5, U4.5
+3V3: C4.1, C13.1, C14.1, C15.1, C16.1, C17.1, C18.1, R1.1, R2.1, R6.2, SW1.2, U1.5, U3.9, U3.24, U3.36, U3.48
+5V: C2.1, C5.1, J3.6, J5.A4, J5.A9, J5.B4, J5.B9, U1.1, U1.3, U2.1, U2.3, U5.5, U6.1
+170V: J3.1, U6.5
+BATT: BT1.1, C1.1, U3.1
BTN: R5.1, R13.1, U3.43, U3.44
GND: BT1.2, C1.2, C2.2, C3.2, C4.2, C5.2, C8.2, C9.2, C10.2, C11.1, C12.2, C13.2, C14.2, C15.2, C16.2, C17.2, C18.2, J1.1, J2.5, J2.7, J2.11, J3.2, J3.3, J3.4, J3.5, J4.R2, J5.A1, J5.A12, J5.B1, J5.B12, J5.S1, R3.2, R4.2, R5.2, R11.2, U1.2, U2.2, U3.8, U3.23, U3.35, U3.47, U4.2, U5.2, U6.3, U6.4
HV_EN: R12.2, U3.18
NX_EN: J3.7, U3.14
NX_RCK: J3.9, U3.16
unnamed: C3.1, U1.4
unnamed: C8.1, U3.3, Y2.2
unnamed: C9.1, U3.4, Y2.1
unnamed: C10.1, U2.4
unnamed: D1.1, R3.1
unnamed: D1.2, U3.45
unnamed: D2.1, R4.1
unnamed: D2.2, U3.46
unnamed: J1.4, R1.2
unnamed: J2.3, R2.2
unnamed: J4.R1, U4.4
unnamed: J4.T, U4.6
unnamed: J5.A6, J5.B6, U5.3
unnamed: J5.A7, J5.B7, U5.1
unnamed: J5.B5, R11.1
unnamed: R7.1, U3.30
unnamed: R7.2, U4.3
unnamed: R8.1, U3.31
unnamed: R8.2, U4.1
unnamed: R9.1, U3.32
unnamed: R9.2, U5.6
unnamed: R6.1, R10.1, U3.33
unnamed: R10.2, U5.4
unnamed: R12.1, U6.2
unnamed: R13.2, SW1.1
RST: C11.2, J1.5, U3.7
SPI1_MOSI: J3.8, U3.17
SPI1_SCK: J3.10, U3.15
T_JTDI: J2.10, U3.38
T_JTDO: J2.8, U3.39
T_NRST: J2.12, U3.40
T_SWCLK: J1.2, J2.6, U3.37
T_SWDIO: J1.3, J2.4, U3.34
T_VCP_RX: J2.13, U3.13
T_VCP_TX: J2.14, U3.12

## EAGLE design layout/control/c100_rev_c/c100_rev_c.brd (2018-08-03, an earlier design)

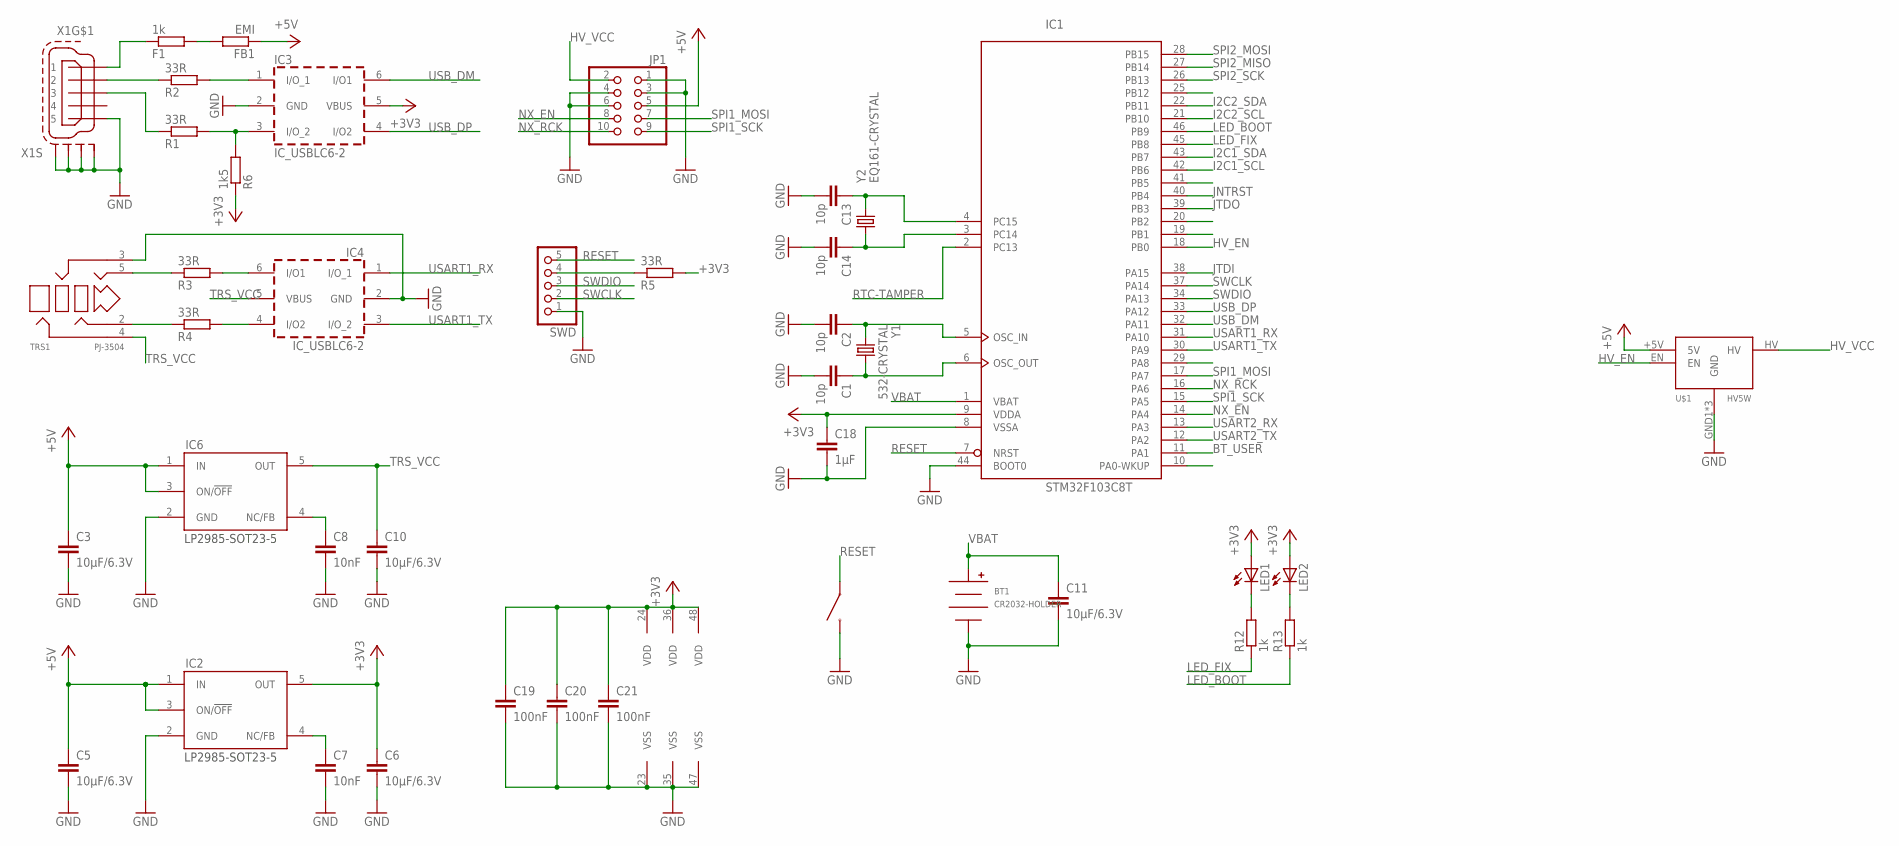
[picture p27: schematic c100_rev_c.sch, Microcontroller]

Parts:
BT1: CR2032-HOLDER; CH28-2032LF
C1, C2, C13, C14: 10p; C0603
C3, C5, C6, C10, C11: 10µF/6.3V; C0603
C7, C8: 10nF; C0603
C18: 1µF; C0603
C19, C20, C21: 100nF; C0603
F1: 1k; R0603
FB1: EMI; R0603
IC1: STM32F103C8T; LQFP48
IC2, IC6: LP2985-SOT23-5; SOT23-5
IC3, IC4: IC_USBLC6-2; SOT-23-6L
ISP: TACT-SWITCH-40-40; 40-40
JP1: PINHD-2X5_2.54-SMD; 2X05SMD
LED1, LED2: LEDCHIP-LED0603; CHIP-LED0603
R1, R2, R3, R4, R5: 33R; R0603
R6: 1k5; R0603
R12, R13: 1k; R0603
SWD: HEADER-1X5ROUND; 1X05_ROUND
TRS1: PJ-3504; YD-PJ-3504
U$1: HV5W; HV5W-D
X1: MINI-USB-SCHIELD-32005-201; 32005-201
Y1: 532-CRYSTAL; 2PIN50X32
Y2: EQ161-CRYSTAL; EQ161

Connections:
+3V3: C6.1, C18.1, C19.1, C20.1, C21.1, IC1.9 (VDDA), IC1.24 (VDD), IC1.36 (VDD), IC1.48 (VDD), IC2.5 (OUT), IC3.5 (VBUS), LED1.A, LED2.A, R5.2, R6.1
+5V: C3.1, C5.1, FB1.1, IC2.1 (IN), IC2.3 (ON/!OFF), IC6.1 (IN), IC6.3 (ON/!OFF), JP1.5, U$1.+5V (5V)
ASDAWJIODJA: R5.1, SWD.4
BT_USER: IC1.11 (PA1)
GND: BT1.NEG, C1.2, C2.2, C3.2, C5.2, C6.2, C7.2, C8.2, C10.2, C11.2, C13.2, C14.2, C18.2, C19.2, C20.2, C21.2, IC1.8 (VSSA), IC1.23 (VSS), IC1.35 (VSS), IC1.44 (BOOT0), IC1.47 (VSS), IC2.2 (GND), IC3.2 (GND), IC4.2 (GND), IC6.2 (GND), ISP.1, ISP.2, JP1.1, JP1.3, JP1.4, JP1.6, SWD.1, TRS1.3, U$1.GND1 (GND), U$1.GND2 (GND), U$1.GND3 (GND), X1.5, X1.M1 (S1), X1.M2 (S2), X1.M3 (S3), X1.M4 (S4)
HV_EN: IC1.18 (PB0), U$1.EN
HV_VCC: JP1.2, U$1.HV
I2C1_SCL: IC1.42 (PB6)
I2C1_SDA: IC1.43 (PB7)
I2C2_SCL: IC1.21 (PB10)
I2C2_SDA: IC1.22 (PB11)
JNTRST: IC1.40 (PB4)
JTDI: IC1.38 (PA15)
JTDO: IC1.39 (PB3)
LED_BOOT: IC1.46 (PB9), R13.1
LED_FIX: IC1.45 (PB8), R12.1
unnamed: C1.1, IC1.6 (OSC_OUT), Y1.P$1 (1)
unnamed: C2.1, IC1.5 (OSC_IN), Y1.P$2 (2)
unnamed: F1.1, X1.1
unnamed: C8.1, IC6.4 (NC/FB)
unnamed: IC3.3 (I/O_2), R1.2, R6.2
unnamed: IC4.6 (I/O1), R3.2
unnamed: LED2.C, R13.2
unnamed: LED1.C, R12.2
unnamed: R4.1, TRS1.2
unnamed: C7.1, IC2.4 (NC/FB)
unnamed: F1.2, FB1.2
unnamed: IC3.1 (I/O_1), R2.2
unnamed: R2.1, X1.2
unnamed: IC4.4 (I/O2), R4.2
unnamed: R3.1, TRS1.5
unnamed: C13.1, IC1.4 (PC15), Y2.P$1 (1)
unnamed: C14.1, IC1.3 (PC14), Y2.P$2 (2)
unnamed: R1.1, X1.3
NX_EN: IC1.14 (PA4), JP1.8
NX_RCK: IC1.16 (PA6), JP1.10
RESET: IC1.7 (NRST), ISP.3, ISP.4, SWD.5
RTC-TAMPER: IC1.2 (PC13)
SPI1_MOSI: IC1.17 (PA7), JP1.7
SPI1_SCK: IC1.15 (PA5), JP1.9
SPI2_MISO: IC1.27 (PB14)
SPI2_MOSI: IC1.28 (PB15)
SPI2_SCK: IC1.26 (PB13)
SWCLK: IC1.37 (PA14), SWD.2
SWDIO: IC1.34 (PA13), SWD.3
TRS_VCC: C10.1, IC4.5 (VBUS), IC6.5 (OUT), TRS1.4
USART1_RX: IC1.31 (PA10), IC4.1 (I/O_1)
USART1_TX: IC1.30 (PA9), IC4.3 (I/O_2)
USART2_RX: IC1.13 (PA3)
USART2_TX: IC1.12 (PA2)
USB_DM: IC1.32 (PA11), IC3.6 (I/O1)
USB_DP: IC1.33 (PA12), IC3.4 (I/O2)
VBAT: BT1.POS, C11.1, IC1.1 (VBAT)

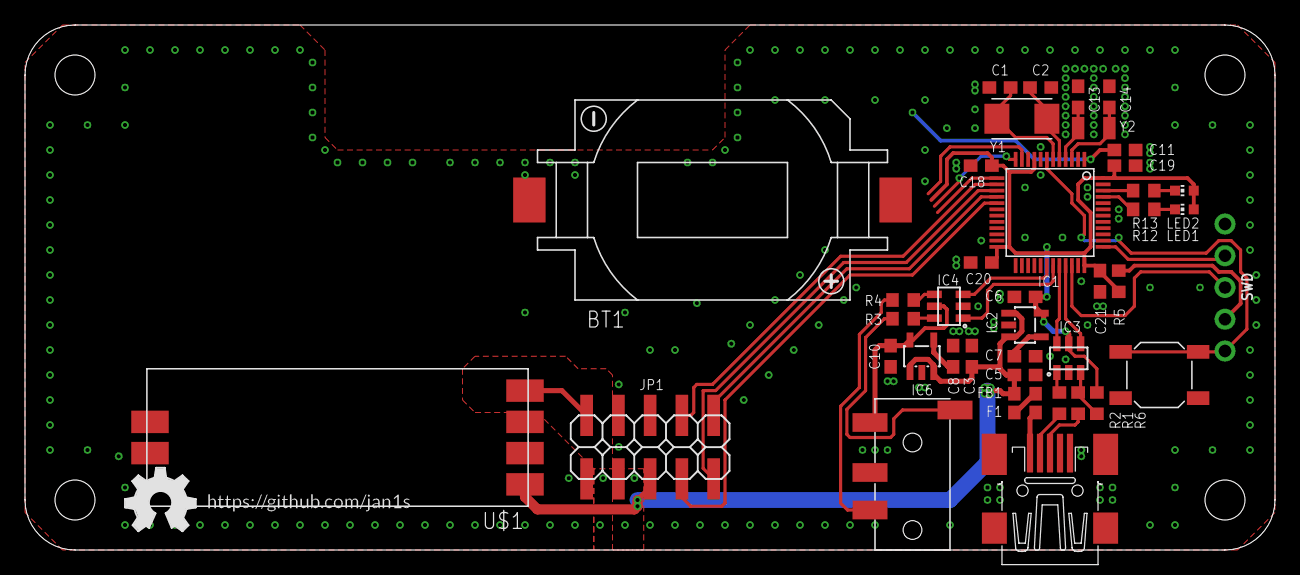
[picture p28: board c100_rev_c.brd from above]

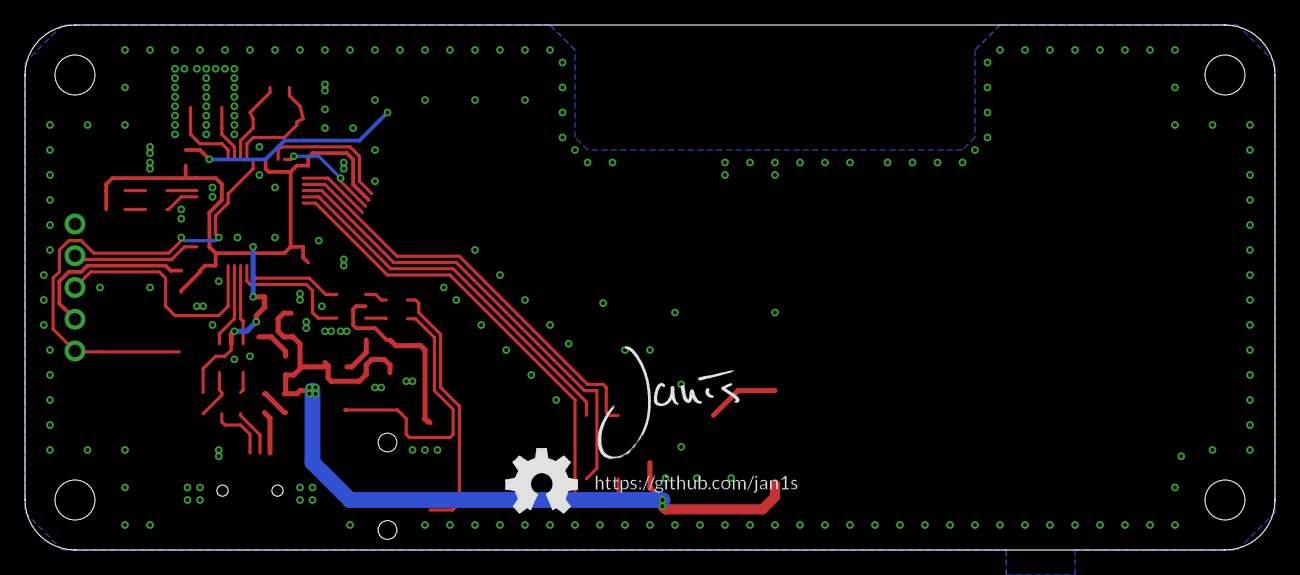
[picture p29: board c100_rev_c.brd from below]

Board: 2 copper layers, 100.0 x 42.0 mm, 46 parts (3 on the bottom side), 39 nets.

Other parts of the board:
LOGO1, LOGO2: OSHW_LOGO_FILLX0200-NT; OSHW_FILLX200_NOTEXT
U$2: JANIS_10MM
U$5, U$6: GITHUB/JAN1S

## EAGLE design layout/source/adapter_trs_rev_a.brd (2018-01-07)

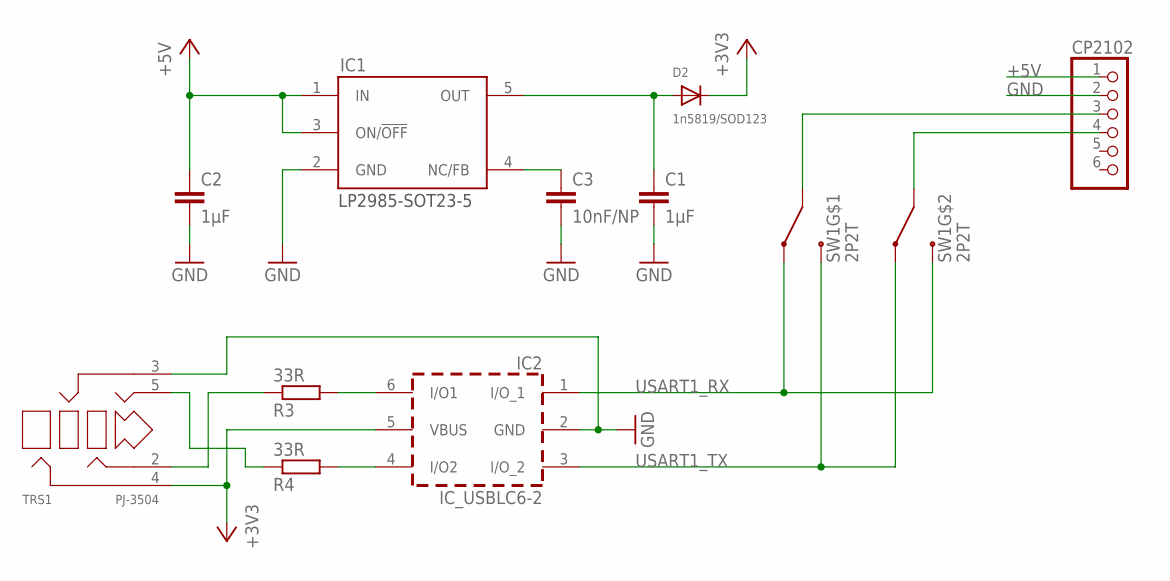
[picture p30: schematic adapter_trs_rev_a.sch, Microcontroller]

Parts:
C1, C2: 1µF; C0603
C3: 10nF/NP; C0603
CP2102: HEADER-1X6ROUND; 1X06_ROUND
D2: 1n5819/SOD123; SOD-123
IC1: LP2985-SOT23-5; SOT23-5
IC2: IC_USBLC6-2; SOT-23-6L
R3, R4: 33R; R0603
SW1: 2P2T; MSS22D18
TRS1: PJ-3504; YD-PJ-3504

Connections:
+3V3: D2.C, IC2.5 (VBUS), TRS1.4
+5V: C2.1, CP2102.1, IC1.1 (IN), IC1.3 (ON/!OFF)
GND: C1.2, C2.2, C3.2, CP2102.2, IC1.2 (GND), IC2.2 (GND), TRS1.3
unnamed: C1.1, D2.A, IC1.5 (OUT)
unnamed: C3.1, IC1.4 (NC/FB)
unnamed: R3.1, TRS1.2
unnamed: CP2102.3, SW1.C1 (C)
unnamed: IC2.6 (I/O1), R3.2
unnamed: R4.1, TRS1.5
unnamed: CP2102.4, SW1.C2 (C)
unnamed: IC2.4 (I/O2), R4.2
USART1_RX: IC2.1 (I/O_1), SW1.A1 (A), SW1.B2 (B)
USART1_TX: IC2.3 (I/O_2), SW1.A2 (A), SW1.B1 (B)

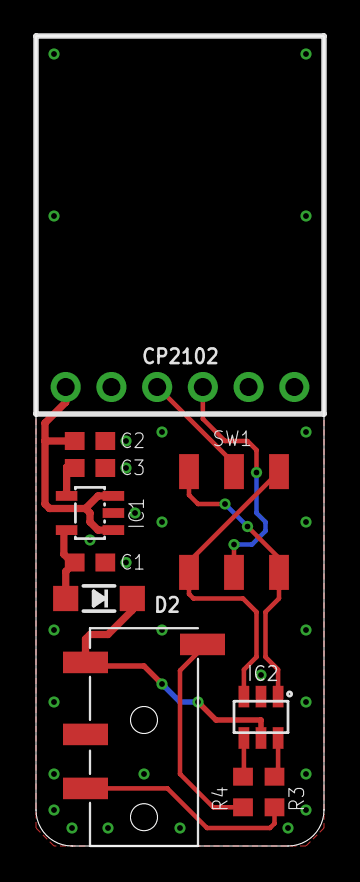
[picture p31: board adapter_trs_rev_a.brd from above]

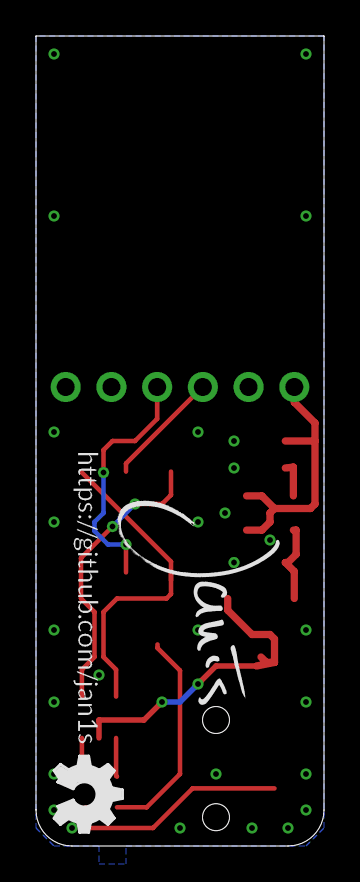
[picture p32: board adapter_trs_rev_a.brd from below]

Board: 2 copper layers, 16.0 x 45.0 mm, 14 parts (3 on the bottom side), 13 nets.

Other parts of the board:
U$1: OSHW_FILLX150_NOTEXT
U$2: JANIS_10MM
U$6: GITHUB/JAN1S

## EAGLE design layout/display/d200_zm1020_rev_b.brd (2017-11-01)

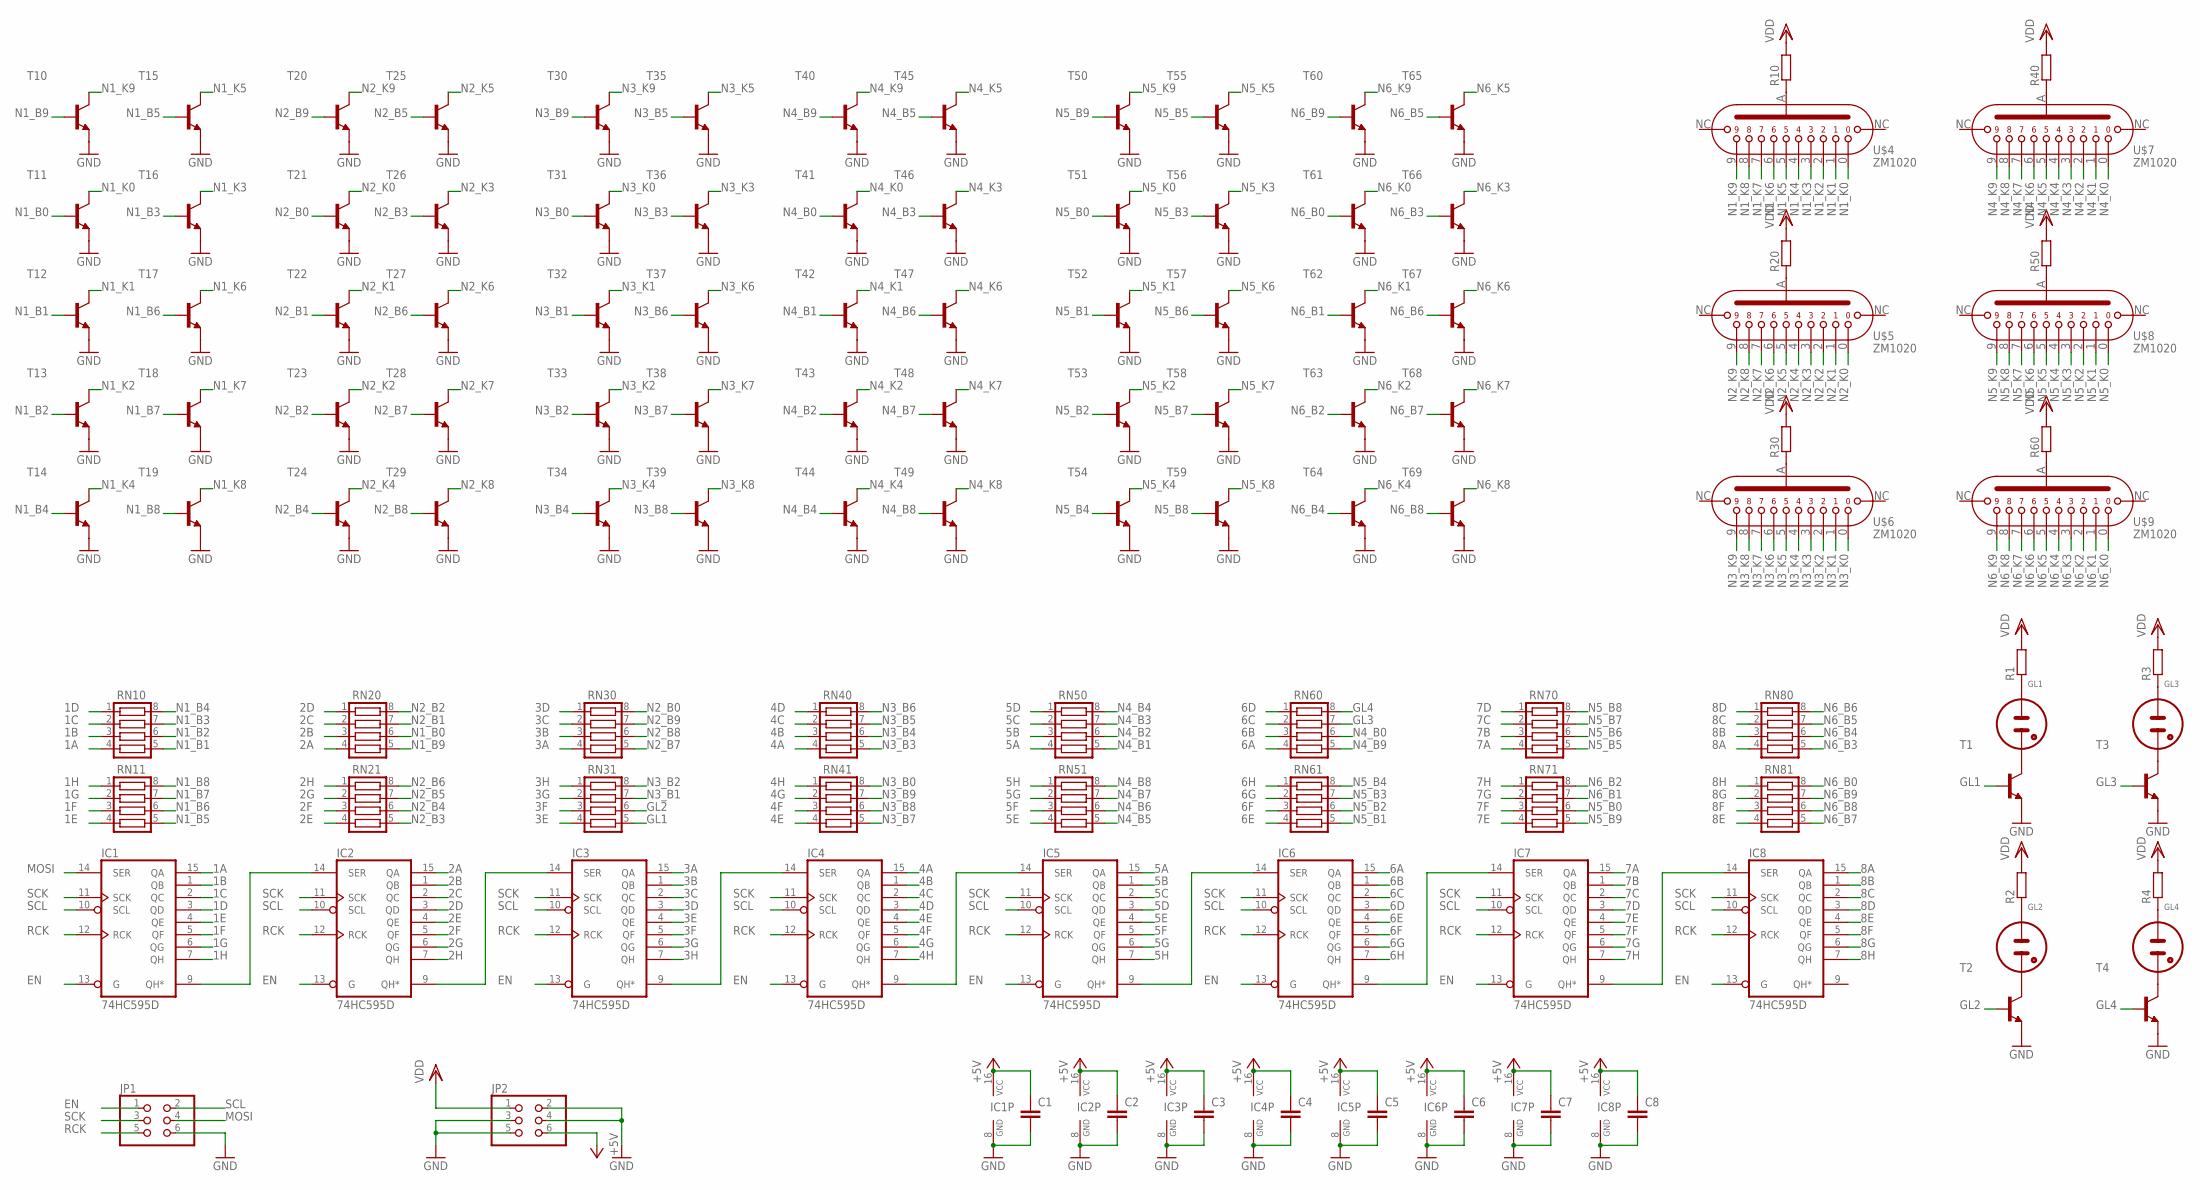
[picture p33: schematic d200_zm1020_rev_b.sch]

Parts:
C1, C2, C3, C4, C5, C6, C7, C8: C-EUC0603; C0603
GL1, GL2, GL3, GL4: NE2-NEON-BULB-DRILL
IC1, IC2, IC3, IC4, IC5, IC6, IC7, IC8: 74HC595D; SO16
JP1, JP2: PINHD-2X3_2.54-SMD; 2X03SMD
R1, R2, R3, R4, R10, R20, R30, R40, R50, R60: R-EU_R0603; R0603
RN10, RN11, RN20, RN21, RN30, RN31, RN40, RN41, RN50, RN51, RN60, RN61, RN70, RN71, RN80, RN81: CTS742C083
T1, T2, T3, T4, T10, T11, T12, T13, T14, T15, T16, T17, T18, T19, T20, T21, T22, T23, T24, T25, T26, T27, T28, T29, T30, T31, T32, T33, T34, T35, T36, T37, T38, T39, T40, T41, T42, T43, T44, T45, T46, T47, T48, T49, T50, T51, T52, T53, T54, T55, T56, T57, T58, T59, T60, T61, T62, T63, T64, T65, T66, T67, T68, T69: SMBTA42; SOT23
U$4, U$5, U$6, U$7, U$8, U$9: ZM1020

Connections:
1A: IC1.15 (QA), RN10.4
1B: IC1.1 (QB), RN10.3
1C: IC1.2 (QC), RN10.2
1D: IC1.3 (QD), RN10.1
1E: IC1.4 (QE), RN11.4
1F: IC1.5 (QF), RN11.3
1G: IC1.6 (QG), RN11.2
1H: IC1.7 (QH), RN11.1
2A: IC2.15 (QA), RN20.4
2B: IC2.1 (QB), RN20.3
2C: IC2.2 (QC), RN20.2
2D: IC2.3 (QD), RN20.1
2E: IC2.4 (QE), RN21.4
2F: IC2.5 (QF), RN21.3
2G: IC2.6 (QG), RN21.2
2H: IC2.7 (QH), RN21.1
3A: IC3.15 (QA), RN30.4
3B: IC3.1 (QB), RN30.3
3C: IC3.2 (QC), RN30.2
3D: IC3.3 (QD), RN30.1
3E: IC3.4 (QE), RN31.4
3F: IC3.5 (QF), RN31.3
3G: IC3.6 (QG), RN31.2
3H: IC3.7 (QH), RN31.1
4A: IC4.15 (QA), RN40.4
4B: IC4.1 (QB), RN40.3
4C: IC4.2 (QC), RN40.2
4D: IC4.3 (QD), RN40.1
4E: IC4.4 (QE), RN41.4
4F: IC4.5 (QF), RN41.3
4G: IC4.6 (QG), RN41.2
4H: IC4.7 (QH), RN41.1
5A: IC5.15 (QA), RN50.4
5B: IC5.1 (QB), RN50.3
5C: IC5.2 (QC), RN50.2
5D: IC5.3 (QD), RN50.1
5E: IC5.4 (QE), RN51.4
5F: IC5.5 (QF), RN51.3
5G: IC5.6 (QG), RN51.2
5H: IC5.7 (QH), RN51.1
6A: IC6.15 (QA), RN60.4
6B: IC6.1 (QB), RN60.3
6C: IC6.2 (QC), RN60.2
6D: IC6.3 (QD), RN60.1
6E: IC6.4 (QE), RN61.4
6F: IC6.5 (QF), RN61.3
6G: IC6.6 (QG), RN61.2
6H: IC6.7 (QH), RN61.1
7A: IC7.15 (QA), RN70.4
7B: IC7.1 (QB), RN70.3
7C: IC7.2 (QC), RN70.2
7D: IC7.3 (QD), RN70.1
7E: IC7.4 (QE), RN71.4
7F: IC7.5 (QF), RN71.3
7G: IC7.6 (QG), RN71.2
7H: IC7.7 (QH), RN71.1
8A: IC8.15 (QA), RN80.4
8B: IC8.1 (QB), RN80.3
8C: IC8.2 (QC), RN80.2
8D: IC8.3 (QD), RN80.1
8E: IC8.4 (QE), RN81.4
8F: IC8.5 (QF), RN81.3
8G: IC8.6 (QG), RN81.2
8H: IC8.7 (QH), RN81.1
+5V: C1.1, C2.1, C3.1, C4.1, C5.1, C6.1, C7.1, C8.1, IC1.16 (VCC), IC2.16 (VCC), IC3.16 (VCC), IC4.16 (VCC), IC5.16 (VCC), IC6.16 (VCC), IC7.16 (VCC), IC8.16 (VCC), JP2.6
EN: IC1.13 (G), IC2.13 (G), IC3.13 (G), IC4.13 (G), IC5.13 (G), IC6.13 (G), IC7.13 (G), IC8.13 (G), JP1.1
GL1: RN31.5, T1.1 (B)
GL2: RN31.6, T2.1 (B)
GL3: RN60.7, T3.1 (B)
GL4: RN60.8, T4.1 (B)
GND: C1.2, C2.2, C3.2, C4.2, C5.2, C6.2, C7.2, C8.2, IC1.8 (GND), IC2.8 (GND), IC3.8 (GND), IC4.8 (GND), IC5.8 (GND), IC6.8 (GND), IC7.8 (GND), IC8.8 (GND), JP1.6, JP2.2, JP2.3, JP2.4, JP2.5, T1.2 (E), T2.2 (E), T3.2 (E), T4.2 (E), T10.2 (E), T11.2 (E), T12.2 (E), T13.2 (E), T14.2 (E), T15.2 (E), T16.2 (E), T17.2 (E), T18.2 (E), T19.2 (E), T20.2 (E), T21.2 (E), T22.2 (E), T23.2 (E), T24.2 (E), T25.2 (E), T26.2 (E), T27.2 (E), T28.2 (E), T29.2 (E), T30.2 (E), T31.2 (E), T32.2 (E), T33.2 (E), T34.2 (E), T35.2 (E), T36.2 (E), T37.2 (E), T38.2 (E), T39.2 (E), T40.2 (E), T41.2 (E), T42.2 (E), T43.2 (E), T44.2 (E), T45.2 (E), T46.2 (E), T47.2 (E), T48.2 (E), T49.2 (E), T50.2 (E), T51.2 (E), T52.2 (E), T53.2 (E), T54.2 (E), T55.2 (E), T56.2 (E), T57.2 (E), T58.2 (E), T59.2 (E), T60.2 (E), T61.2 (E), T62.2 (E), T63.2 (E), T64.2 (E), T65.2 (E), T66.2 (E), T67.2 (E), T68.2 (E), T69.2 (E)
MOSI: IC1.14 (SER), JP1.4
N1_B0: RN20.6, T11.1 (B)
N1_B1: RN10.5, T12.1 (B)
N1_B2: RN10.6, T13.1 (B)
N1_B3: RN10.7, T16.1 (B)
N1_B4: RN10.8, T14.1 (B)
N1_B5: RN11.5, T15.1 (B)
N1_B6: RN11.6, T17.1 (B)
N1_B7: RN11.7, T18.1 (B)
N1_B8: RN11.8, T19.1 (B)
N1_B9: RN20.5, T10.1 (B)
N1_K0: T11.3 (C), U$4.P3 (0)
N1_K1: T12.3 (C), U$4.P13 (1)
N1_K2: T13.3 (C), U$4.P12 (2)
N1_K3: T16.3 (C), U$4.P11 (3)
N1_K4: T14.3 (C), U$4.P10 (4)
N1_K5: T15.3 (C), U$4.P9 (5)
N1_K6: T17.3 (C), U$4.P7 (6)
N1_K7: T18.3 (C), U$4.P6 (7)
N1_K8: T19.3 (C), U$4.P5 (8)
N1_K9: T10.3 (C), U$4.P4 (9)
N2_B0: RN30.8, T21.1 (B)
N2_B1: RN20.7, T22.1 (B)
N2_B2: RN20.8, T23.1 (B)
N2_B3: RN21.5, T26.1 (B)
N2_B4: RN21.6, T24.1 (B)
N2_B5: RN21.7, T25.1 (B)
N2_B6: RN21.8, T27.1 (B)
N2_B7: RN30.5, T28.1 (B)
N2_B8: RN30.6, T29.1 (B)
N2_B9: RN30.7, T20.1 (B)
N2_K0: T21.3 (C), U$5.P3 (0)
N2_K1: T22.3 (C), U$5.P13 (1)
N2_K2: T23.3 (C), U$5.P12 (2)
N2_K3: T26.3 (C), U$5.P11 (3)
N2_K4: T24.3 (C), U$5.P10 (4)
N2_K5: T25.3 (C), U$5.P9 (5)
N2_K6: T27.3 (C), U$5.P7 (6)
N2_K7: T28.3 (C), U$5.P6 (7)
N2_K8: T29.3 (C), U$5.P5 (8)
N2_K9: T20.3 (C), U$5.P4 (9)
N3_B0: RN41.8, T31.1 (B)
N3_B1: RN31.7, T32.1 (B)
N3_B2: RN31.8, T33.1 (B)
N3_B3: RN40.5, T36.1 (B)
N3_B4: RN40.6, T34.1 (B)
N3_B5: RN40.7, T35.1 (B)
N3_B6: RN40.8, T37.1 (B)
N3_B7: RN41.5, T38.1 (B)
N3_B8: RN41.6, T39.1 (B)
N3_B9: RN41.7, T30.1 (B)
N3_K0: T31.3 (C), U$6.P3 (0)
N3_K1: T32.3 (C), U$6.P13 (1)
N3_K2: T33.3 (C), U$6.P12 (2)
N3_K3: T36.3 (C), U$6.P11 (3)
N3_K4: T34.3 (C), U$6.P10 (4)
N3_K5: T35.3 (C), U$6.P9 (5)
N3_K6: T37.3 (C), U$6.P7 (6)
N3_K7: T38.3 (C), U$6.P6 (7)
N3_K8: T39.3 (C), U$6.P5 (8)
N3_K9: T30.3 (C), U$6.P4 (9)
N4_B0: RN60.6, T41.1 (B)
N4_B1: RN50.5, T42.1 (B)
N4_B2: RN50.6, T43.1 (B)
N4_B3: RN50.7, T46.1 (B)
N4_B4: RN50.8, T44.1 (B)
N4_B5: RN51.5, T45.1 (B)
N4_B6: RN51.6, T47.1 (B)
N4_B7: RN51.7, T48.1 (B)
N4_B8: RN51.8, T49.1 (B)
N4_B9: RN60.5, T40.1 (B)
N4_K0: T41.3 (C), U$7.P3 (0)
N4_K1: T42.3 (C), U$7.P13 (1)
N4_K2: T43.3 (C), U$7.P12 (2)
N4_K3: T46.3 (C), U$7.P11 (3)
N4_K4: T44.3 (C), U$7.P10 (4)
N4_K5: T45.3 (C), U$7.P9 (5)
N4_K6: T47.3 (C), U$7.P7 (6)
N4_K7: T48.3 (C), U$7.P6 (7)
N4_K8: T49.3 (C), U$7.P5 (8)
N4_K9: T40.3 (C), U$7.P4 (9)
N5_B0: RN71.6, T51.1 (B)
N5_B1: RN61.5, T52.1 (B)
N5_B2: RN61.6, T53.1 (B)
N5_B3: RN61.7, T56.1 (B)
N5_B4: RN61.8, T54.1 (B)
N5_B5: RN70.5, T55.1 (B)
N5_B6: RN70.6, T57.1 (B)
N5_B7: RN70.7, T58.1 (B)
N5_B8: RN70.8, T59.1 (B)
N5_B9: RN71.5, T50.1 (B)
N5_K0: T51.3 (C), U$8.P3 (0)
N5_K1: T52.3 (C), U$8.P13 (1)
N5_K2: T53.3 (C), U$8.P12 (2)
N5_K3: T56.3 (C), U$8.P11 (3)
N5_K4: T54.3 (C), U$8.P10 (4)
N5_K5: T55.3 (C), U$8.P9 (5)
N5_K6: T57.3 (C), U$8.P7 (6)
N5_K7: T58.3 (C), U$8.P6 (7)
N5_K8: T59.3 (C), U$8.P5 (8)
N5_K9: T50.3 (C), U$8.P4 (9)
N6_B0: RN81.8, T61.1 (B)
N6_B1: RN71.7, T62.1 (B)
N6_B2: RN71.8, T63.1 (B)
N6_B3: RN80.5, T66.1 (B)
N6_B4: RN80.6, T64.1 (B)
N6_B5: RN80.7, T65.1 (B)
N6_B6: RN80.8, T67.1 (B)
N6_B7: RN81.5, T68.1 (B)
N6_B8: RN81.6, T69.1 (B)
N6_B9: RN81.7, T60.1 (B)
N6_K0: T61.3 (C), U$9.P3 (0)
N6_K1: T62.3 (C), U$9.P13 (1)
N6_K2: T63.3 (C), U$9.P12 (2)
N6_K3: T66.3 (C), U$9.P11 (3)
N6_K4: T64.3 (C), U$9.P10 (4)
N6_K5: T65.3 (C), U$9.P9 (5)
N6_K6: T67.3 (C), U$9.P7 (6)
N6_K7: T68.3 (C), U$9.P6 (7)
N6_K8: T69.3 (C), U$9.P5 (8)
N6_K9: T60.3 (C), U$9.P4 (9)
unnamed: GL2.1 (A), R2.1
unnamed: GL3.1 (A), R3.1
unnamed: GL4.1 (A), R4.1
unnamed: R10.1, U$4.P2 (A)
unnamed: GL2.2 (A1), T2.3 (C)
unnamed: GL1.2 (A1), T1.3 (C)
unnamed: GL4.2 (A1), T4.3 (C)
unnamed: GL3.2 (A1), T3.3 (C)
unnamed: R20.1, U$5.P2 (A)
unnamed: IC1.9 (QH*), IC2.14 (SER)
unnamed: IC2.9 (QH*), IC3.14 (SER)
unnamed: IC3.9 (QH*), IC4.14 (SER)
unnamed: R30.1, U$6.P2 (A)
unnamed: R40.1, U$7.P2 (A)
unnamed: R50.1, U$8.P2 (A)
unnamed: IC4.9 (QH*), IC5.14 (SER)
unnamed: R60.1, U$9.P2 (A)
unnamed: IC5.9 (QH*), IC6.14 (SER)
unnamed: IC6.9 (QH*), IC7.14 (SER)
unnamed: IC7.9 (QH*), IC8.14 (SER)
unnamed: GL1.1 (A), R1.1
RCK: IC1.12 (RCK), IC2.12 (RCK), IC3.12 (RCK), IC4.12 (RCK), IC5.12 (RCK), IC6.12 (RCK), IC7.12 (RCK), IC8.12 (RCK), JP1.5
SCK: IC1.11 (SCK), IC2.11 (SCK), IC3.11 (SCK), IC4.11 (SCK), IC5.11 (SCK), IC6.11 (SCK), IC7.11 (SCK), IC8.11 (SCK), JP1.3
SCL: IC1.10 (SCL), IC2.10 (SCL), IC3.10 (SCL), IC4.10 (SCL), IC5.10 (SCL), IC6.10 (SCL), IC7.10 (SCL), IC8.10 (SCL), JP1.2
VDD: JP2.1, R1.2, R2.2, R3.2, R4.2, R10.2, R20.2, R30.2, R40.2, R50.2, R60.2

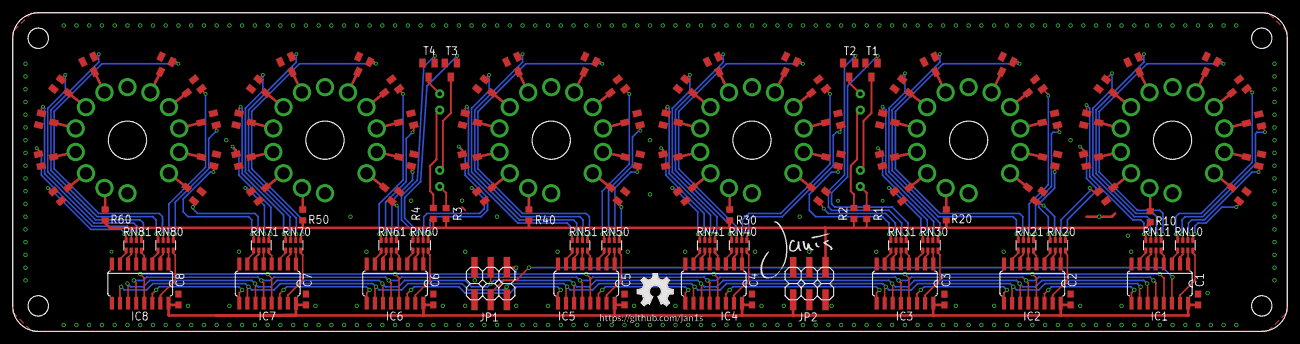
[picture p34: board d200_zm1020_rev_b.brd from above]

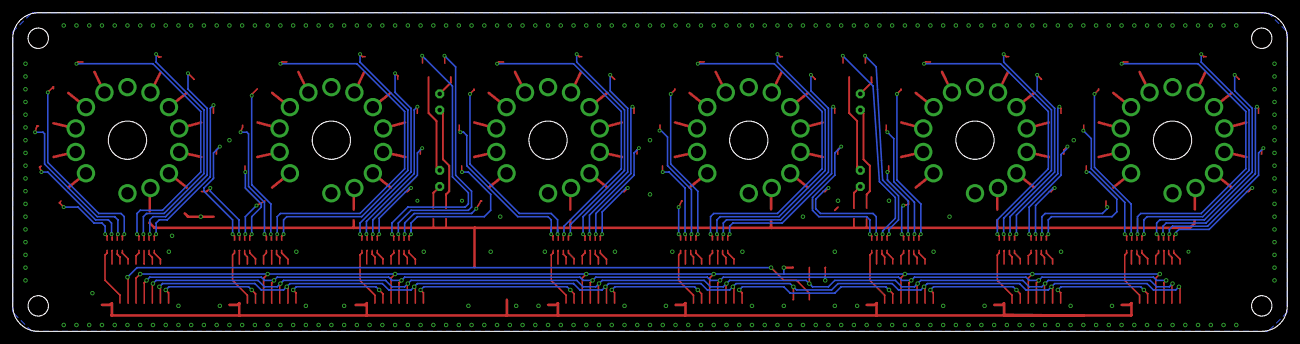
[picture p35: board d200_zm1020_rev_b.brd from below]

Board: 2 copper layers, 200.0 x 50.0 mm, 121 parts (10 on the bottom side), 217 nets.

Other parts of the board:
U$1: OSHW_FILLX200_NOTEXT
U$2: JANIS_10MM
U$3: GITHUB/JAN1S

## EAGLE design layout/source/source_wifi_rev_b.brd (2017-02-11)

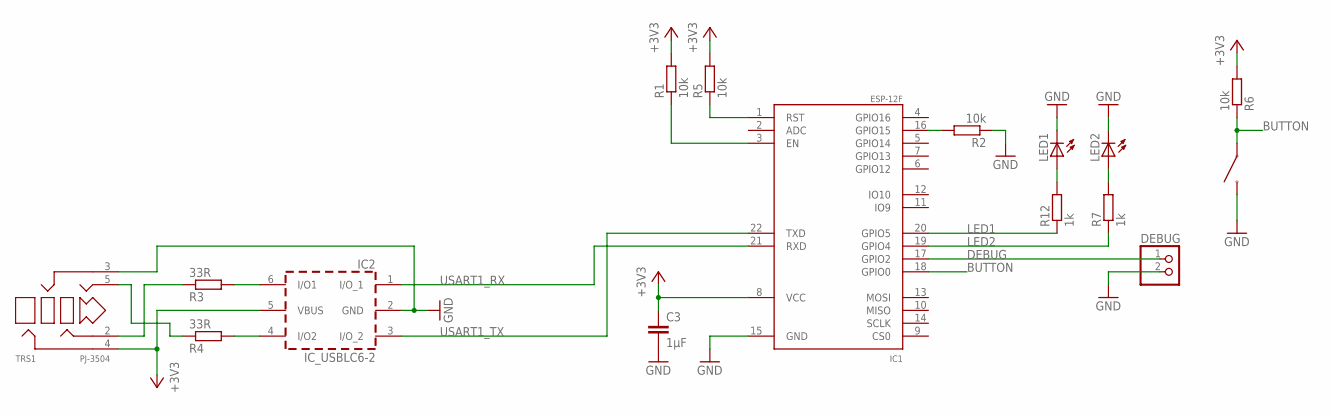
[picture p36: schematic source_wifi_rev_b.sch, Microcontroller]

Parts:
C3: 1µF; C0603
DEBUG: HEADER-1X2ROUND; 1X02_ROUND
IC1: ESP-12F
IC2: IC_USBLC6-2; SOT-23-6L
ISP: TACT-SWITCH-40-40; 40-40
LED1, LED2: LEDCHIP-LED0603; CHIP-LED0603
R1, R2, R5, R6: 10k; R0603
R3, R4: 33R; R0603
R7, R12: 1k; R0603
TRS1: PJ-3504; YD-PJ-3504

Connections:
+3V3: C3.1, IC1.8 (VCC), IC2.5 (VBUS), R1.2, R5.2, R6.2, TRS1.4
BUTTON: IC1.18 (GPIO0), ISP.3, ISP.4, R6.1
DEBUG: DEBUG.1, IC1.17 (GPIO2)
GND: C3.2, DEBUG.2, IC1.15 (GND), IC2.2 (GND), ISP.1, ISP.2, LED1.C, LED2.C, R2.1, TRS1.3
LED1: IC1.20 (GPIO5), R12.1
LED2: IC1.19 (GPIO4), R7.1
unnamed: IC1.3 (EN), R1.1
unnamed: IC1.16 (GPIO15), R2.2
unnamed: IC1.1 (RST), R5.1
unnamed: R3.1, TRS1.2
unnamed: LED2.A, R7.2
unnamed: LED1.A, R12.2
unnamed: IC2.6 (I/O1), R3.2
unnamed: R4.1, TRS1.5
unnamed: IC2.4 (I/O2), R4.2
USART1_RX: IC1.21 (RXD), IC2.1 (I/O_1)
USART1_TX: IC1.22 (TXD), IC2.3 (I/O_2)

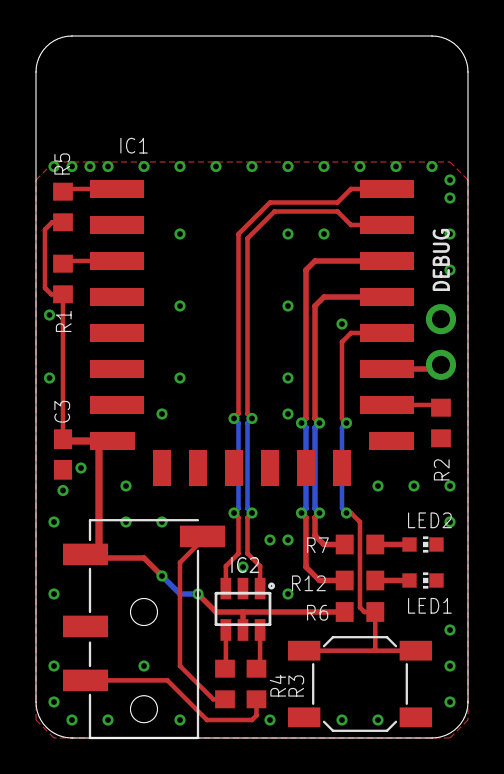
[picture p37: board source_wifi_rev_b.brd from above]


Board: 2 copper layers, 24.0 x 39.0 mm, 19 parts (3 on the bottom side), 17 nets.

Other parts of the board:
U$1: OSHW_FILLX150_NOTEXT
U$2: JANIS_10MM
U$6: GITHUB/JAN1S

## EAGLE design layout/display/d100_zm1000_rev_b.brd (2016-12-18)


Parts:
C1, C2, C3, C4, C5, C6: C-EUC0603; C0603
GL1, GL2: NE2-NEON-BULB-DRILL
IC1, IC2, IC3, IC4, IC5, IC6: 74HC595PW; TSSOP16
JP1: PINHD-2X5_2.54-SMD; 2X05SMD
N1, N2, N3, N4: ZM1000-SOCKETED
R1, R2, R10, R11, R20, R21, R30, R31, R40, R41: R-EU_R0603; R0603
RN10, RN11, RN20, RN21, RN30, RN31, RN40, RN41, RN50, RN51, RN60, RN61: 10k; CTS742C083
T1, T2, T10, T11, T12, T13, T14, T15, T16, T17, T18, T19, T20, T21, T22, T23, T24, T25, T26, T27, T28, T29, T30, T31, T32, T33, T34, T35, T36, T37, T38, T39, T40, T41, T42, T43, T44, T45, T46, T47, T48, T49: SMBTA42; SOT23

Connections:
1A: IC1.15 (QA), RN10.4
1B: IC1.1 (QB), RN10.3
1B0: RN11.8, T10.1 (B)
1B1: RN11.5, T11.1 (B)
1B2: RN10.8, T12.1 (B)
1B3: RN10.7, T13.1 (B)
1B4: RN10.6, T14.1 (B)
1B5: RN10.5, T15.1 (B)
1B6: RN20.6, T16.1 (B)
1B7: RN20.5, T17.1 (B)
1B8: RN11.6, T18.1 (B)
1B9: RN11.7, T19.1 (B)
1C: IC1.2 (QC), RN10.2
1D: IC1.3 (QD), RN10.1
1E: IC1.4 (QE), RN11.4
1F: IC1.5 (QF), RN11.3
1G: IC1.6 (QG), RN11.2
1H: IC1.7 (QH), RN11.1
2A: IC2.15 (QA), RN20.4
2B: IC2.1 (QB), RN20.3
2B0: RN30.6, T20.1 (B)
2B1: RN21.7, T21.1 (B)
2B2: RN21.6, T22.1 (B)
2B3: RN21.5, T23.1 (B)
2B4: RN20.8, T24.1 (B)
2B5: RN20.7, T25.1 (B)
2B6: RN30.8, T26.1 (B)
2B7: RN30.7, T27.1 (B)
2B8: RN21.8, T28.1 (B)
2B9: RN30.5, T29.1 (B)
2C: IC2.2 (QC), RN20.2
2D: IC2.3 (QD), RN20.1
2E: IC2.4 (QE), RN21.4
2F: IC2.5 (QF), RN21.3
2G: IC2.6 (QG), RN21.2
2H: IC2.7 (QH), RN21.1
3A: IC3.15 (QA), RN30.4
3B: IC3.1 (QB), RN30.3
3B0: RN41.8, T30.1 (B)
3B1: RN41.5, T31.1 (B)
3B2: RN40.8, T32.1 (B)
3B3: RN40.7, T33.1 (B)
3B4: RN40.6, T34.1 (B)
3B5: RN40.5, T35.1 (B)
3B6: RN50.6, T36.1 (B)
3B7: RN50.5, T37.1 (B)
3B8: RN41.6, T38.1 (B)
3B9: RN41.7, T39.1 (B)
3C: IC3.2 (QC), RN30.2
3D: IC3.3 (QD), RN30.1
3E: IC3.4 (QE), RN31.4
3F: IC3.5 (QF), RN31.3
3G: IC3.6 (QG), RN31.2
3H: IC3.7 (QH), RN31.1
4A: IC4.15 (QA), RN40.4
4B: IC4.1 (QB), RN40.3
4B0: RN60.6, T40.1 (B)
4B1: RN51.7, T41.1 (B)
4B2: RN51.6, T42.1 (B)
4B3: RN51.5, T43.1 (B)
4B4: RN50.8, T44.1 (B)
4B5: RN50.7, T45.1 (B)
4B6: RN60.8, T46.1 (B)
4B7: RN60.7, T47.1 (B)
4B8: RN51.8, T48.1 (B)
4B9: RN60.5, T49.1 (B)
4C: IC4.2 (QC), RN40.2
4D: IC4.3 (QD), RN40.1
4E: IC4.4 (QE), RN41.4
4F: IC4.5 (QF), RN41.3
4G: IC4.6 (QG), RN41.2
4H: IC4.7 (QH), RN41.1
5A: IC5.15 (QA), RN50.4
5B: IC5.1 (QB), RN50.3
5B2: RN61.8
5B3: RN61.7
5B4: RN61.6
5B5: RN61.5
5C: IC5.2 (QC), RN50.2
5D: IC5.3 (QD), RN50.1
5E: IC5.4 (QE), RN51.4
5F: IC5.5 (QF), RN51.3
5G: IC5.6 (QG), RN51.2
5H: IC5.7 (QH), RN51.1
6A: IC6.15 (QA), RN60.4
6B: IC6.1 (QB), RN60.3
6C: IC6.2 (QC), RN60.2
6D: IC6.3 (QD), RN60.1
6E: IC6.4 (QE), RN61.4
6F: IC6.5 (QF), RN61.3
6G: IC6.6 (QG), RN61.2
6H: IC6.7 (QH), RN61.1
+5V: C1.1, C2.1, C3.1, C4.1, C5.1, C6.1, IC1.10 (SCL), IC1.16 (VCC), IC2.10 (SCL), IC2.16 (VCC), IC3.10 (SCL), IC3.16 (VCC), IC4.10 (SCL), IC4.16 (VCC), IC5.10 (SCL), IC5.16 (VCC), IC6.10 (SCL), IC6.16 (VCC), JP1.6
EN: IC1.13 (G), IC2.13 (G), IC3.13 (G), IC4.13 (G), IC5.13 (G), IC6.13 (G), JP1.7
GL1: RN31.5, T1.1 (B)
GL2: RN31.6, T2.1 (B)
GND: C1.2, C2.2, C3.2, C4.2, C5.2, C6.2, IC1.8 (GND), IC2.8 (GND), IC3.8 (GND), IC4.8 (GND), IC5.8 (GND), IC6.8 (GND), JP1.2, JP1.3, JP1.4, JP1.5, R11.1, R21.1, R31.1, R41.1, T1.2 (E), T2.2 (E), T10.2 (E), T11.2 (E), T12.2 (E), T13.2 (E), T14.2 (E), T15.2 (E), T16.2 (E), T17.2 (E), T18.2 (E), T19.2 (E), T20.2 (E), T21.2 (E), T22.2 (E), T23.2 (E), T24.2 (E), T25.2 (E), T26.2 (E), T27.2 (E), T28.2 (E), T29.2 (E), T30.2 (E), T31.2 (E), T32.2 (E), T33.2 (E), T34.2 (E), T35.2 (E), T36.2 (E), T37.2 (E), T38.2 (E), T39.2 (E), T40.2 (E), T41.2 (E), T42.2 (E), T43.2 (E), T44.2 (E), T45.2 (E), T46.2 (E), T47.2 (E), T48.2 (E), T49.2 (E)
MOSI: IC1.14 (SER), JP1.8
N1_0: N1.K0 (0), T10.3 (C)
N1_1: N1.K1 (1), T11.3 (C)
N1_2: N1.K2 (2), T12.3 (C)
N1_3: N1.K3 (3), T13.3 (C)
N1_4: N1.K4 (4), T14.3 (C)
N1_5: N1.K5 (5), T15.3 (C)
N1_6: N1.K6 (6), T16.3 (C)
N1_7: N1.K7 (7), T17.3 (C)
N1_8: N1.K8 (8), T18.3 (C)
N1_9: N1.K9 (9), T19.3 (C)
N1_DP: N1.KDP (DP)
N1_PR: N1.PR, R11.2
N2_0: N2.K0 (0), T20.3 (C)
N2_1: N2.K1 (1), T21.3 (C)
N2_2: N2.K2 (2), T22.3 (C)
N2_3: N2.K3 (3), T23.3 (C)
N2_4: N2.K4 (4), T24.3 (C)
N2_5: N2.K5 (5), T25.3 (C)
N2_6: N2.K6 (6), T26.3 (C)
N2_7: N2.K7 (7), T27.3 (C)
N2_8: N2.K8 (8), T28.3 (C)
N2_9: N2.K9 (9), T29.3 (C)
N3_0: N3.K0 (0), T30.3 (C)
N3_1: N3.K1 (1), T31.3 (C)
N3_2: N3.K2 (2), T32.3 (C)
N3_3: N3.K3 (3), T33.3 (C)
N3_4: N3.K4 (4), T34.3 (C)
N3_5: N3.K5 (5), T35.3 (C)
N3_6: N3.K6 (6), T36.3 (C)
N3_7: N3.K7 (7), T37.3 (C)
N3_8: N3.K8 (8), T38.3 (C)
N3_9: N3.K9 (9), T39.3 (C)
N4_0: N4.K0 (0), T40.3 (C)
N4_1: N4.K1 (1), T41.3 (C)
N4_2: N4.K2 (2), T42.3 (C)
N4_3: N4.K3 (3), T43.3 (C)
N4_4: N4.K4 (4), T44.3 (C)
N4_5: N4.K5 (5), T45.3 (C)
N4_6: N4.K6 (6), T46.3 (C)
N4_7: N4.K7 (7), T47.3 (C)
N4_8: N4.K8 (8), T48.3 (C)
N4_9: N4.K9 (9), T49.3 (C)
unnamed: GL2.1 (A), R2.1
unnamed: N1.A1 (A), N1.A2 (A), R10.1
unnamed: GL2.2 (A1), T2.3 (C)
unnamed: GL1.2 (A1), T1.3 (C)
unnamed: N2.A1 (A), N2.A2 (A), R20.1
unnamed: IC1.9 (QH*), IC2.14 (SER)
unnamed: IC2.9 (QH*), IC3.14 (SER)
unnamed: IC3.9 (QH*), IC4.14 (SER)
unnamed: N3.A1 (A), N3.A2 (A), R30.1
unnamed: N4.A1 (A), N4.A2 (A), R40.1
unnamed: IC4.9 (QH*), IC5.14 (SER)
unnamed: IC5.9 (QH*), IC6.14 (SER)
unnamed: GL1.1 (A), R1.1
unnamed: N3.PR, R31.2
unnamed: N2.PR, R21.2
unnamed: N4.PR, R41.2
RCK: IC1.12 (RCK), IC2.12 (RCK), IC3.12 (RCK), IC4.12 (RCK), IC5.12 (RCK), IC6.12 (RCK), JP1.9
SCK: IC1.11 (SCK), IC2.11 (SCK), IC3.11 (SCK), IC4.11 (SCK), IC5.11 (SCK), IC6.11 (SCK), JP1.10
VDD: JP1.1, R1.2, R2.2, R10.2, R20.2, R30.2, R40.2

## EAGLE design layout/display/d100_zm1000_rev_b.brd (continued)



Board: 2 copper layers, 100.0 x 42.0 mm, 86 parts (6 on the bottom side), 154 nets.

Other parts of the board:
U$1: GITHUB/JAN1S
U$2: JANIS_10MM
U$3: OSHW_FILLX200_NOTEXT

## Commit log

2015-11-17 Added control pcb render
2015-11-17 Added case
    [ncase_rev_a.FCStd, ncase_rev_a.stl]
2015-11-17 Added BT timesource
    [source_bt_rev_a.GBL, source_bt_rev_a.GBO, source_bt_rev_a.GBP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]
2015-12-08 Added BOM list
2015-12-08 Fixed values
    [control.brd, control.sch]
2015-12-30 Fixes in case
    [ncase_rev_a.FCStd, ncase_rev_a.stl]
2015-12-31 Fixed display bug
    [display_zm1325.brd, display_zm1325.sch]
2016-01-02 Changed structure, added HM-11
    [control_100.brd, control_100.sch, control_100_rev_a.brd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]
2016-01-03 Changed structure, added c150 and c200
    [c100_rev_a.brd, c100_rev_a.sch, c100_rev_b.brd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]
2016-01-03 C100 production ready
    [c100_rev_b.GBL, c100_rev_b.GBO, c100_rev_b.GBP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]
2016-01-03 Finished c150 rev a
    [c150_rev_a.brd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]
2016-01-03 Added control pcb readme
2016-01-03 Added display readme
    [d100_zm1000_rev_b.brd, d100_zm1000_rev_b.sch, d100_zm1325_rev_b.brd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]
2016-01-17 Fixed naming
    [d100_zm1000_rev_b.brd, d100_zm1000_rev_b.sch]
2016-12-18 Added ESP-12
    [c200.brd, c200.sch]
2016-12-18 Added final c200 production files
    [c200.GBL, c200.GBO, c200.GBP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]
2016-12-29 Added Wifi Module
    [source_wifi_rev_a.GBL, source_wifi_rev_a.GBO, source_wifi_rev_a.GBP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]
2017-02-11 Fixed RX/TX
    [source_wifi.brd, source_wifi.sch]
2017-09-01 Added updated wifi source
    [source_wifi_rev_b.GBL, source_wifi_rev_b.GBO, source_wifi_rev_b.GBP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]
2017-10-22 Added rev. B, Fixed connector distance...
    [c200_rev_b.brd, c200_rev_b.sch]
2017-11-01 Added rev. B of large clock layouts
    [c200_rev_b.sch, d200_zm1020_rev_b.brd, d200_zm1020_rev_b.sch]
2018-01-07 Added new control board versions and TRS adapter
    [adapter_trs_rev_a.GBL, adapter_trs_rev_a.GBO, adapter_trs_rev_a.GBP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]
2018-08-03 Added new c150 board
    [c100_rev_c.brd, c100_rev_c.sch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]
2018-08-03 C200 missing..
    [c200_rev_b.sch]
2018-08-03 Added HV module
    [c200_rev_b.brd, c200_rev_b.sch]
2020-02-05 Added c100_rev_e
    [c100_rev_a.brd, c100_rev_a.sch, c100_rev_b.brd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]

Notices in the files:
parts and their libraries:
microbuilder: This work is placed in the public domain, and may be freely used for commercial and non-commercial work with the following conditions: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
